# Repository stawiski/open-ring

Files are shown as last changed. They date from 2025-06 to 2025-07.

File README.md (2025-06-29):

<picture>
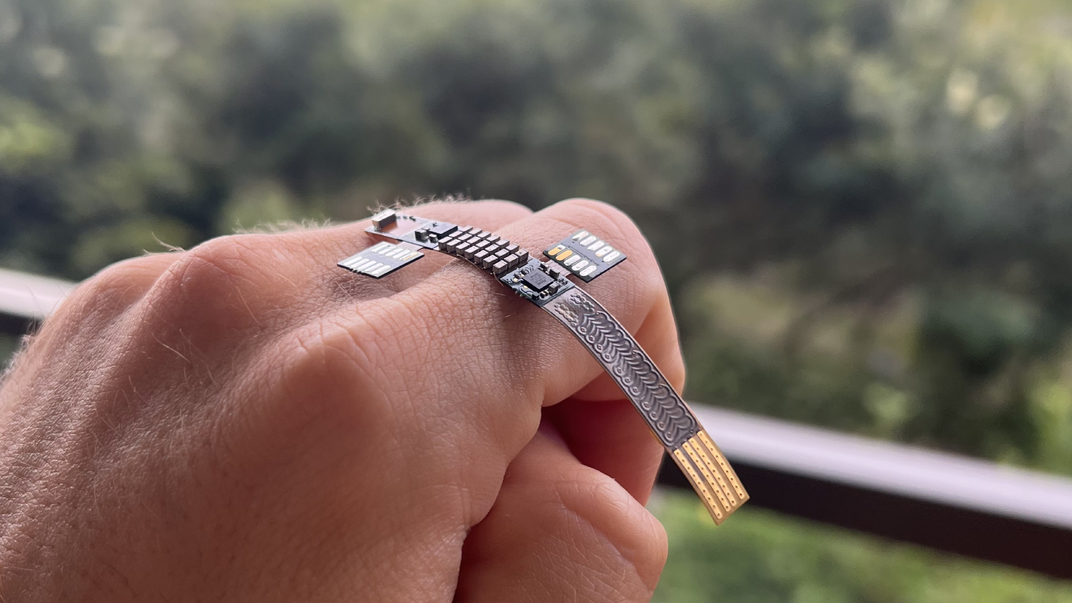
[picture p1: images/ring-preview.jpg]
Shows the Open Ring project hardware
  
</picture>

<h1 align="center">Open Ring - the open source Smart Ring project</h1>




Open Ring is an open hardware and firmware smart ring project. It is a wearable device that can be used to control any BLE connected device (e.g. your phone or computer). It can also be used as a reference for designing other smart ring projects.

# Overview

Open Ring is state-of-the-art smart ring project featuring:
- Ultra low power BLE 5.1
- Capacitive touch sensing for gestures
- Haptic feedback
- Wireless induction charging (with a separate charger)
- Wear detection

All in an absolutely tiny form factor to fit in a ring of less than 3mm thickness (a typical wedding band).
Ring sizes range from US6 to US13.

<picture>
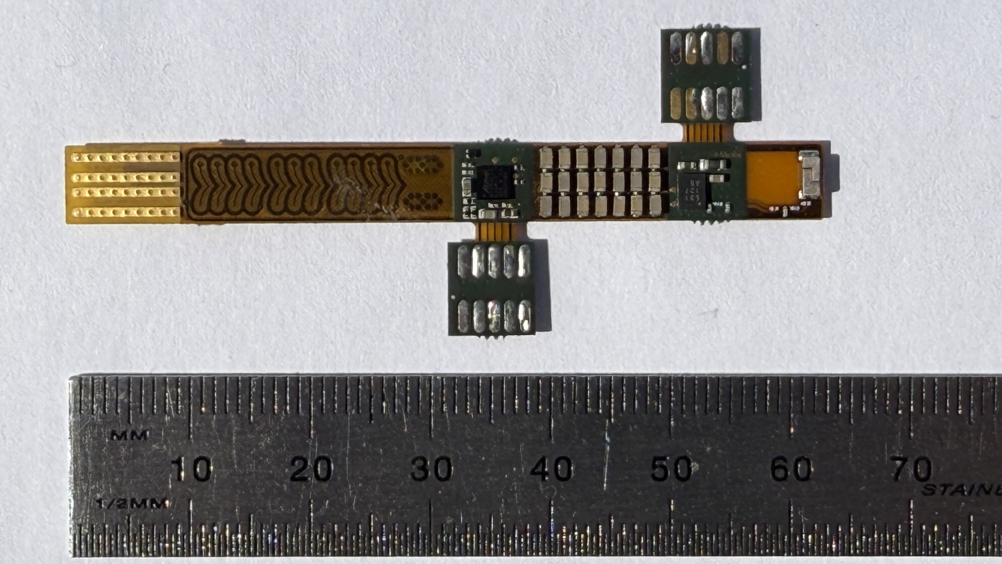
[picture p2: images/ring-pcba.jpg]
Shows the Open Ring project hardware
  
</picture>

## Status

Current project status:
- ✅ First article on Memfault has been published ([link to article](https://interrupt.memfault.com/blog/smart-ring-development-part-1))
- ✅ Hardware release

Remaining TODOs:
- Second article on Memfault about hardware development
- Third article on Memfault about firmware development + firmware release
- Update firmware builds (Docker based)
- Update README

## Hardware

Open Ring uses:
- Dialog DA14531 BLE SoC
- Atmel ATSAML10E16A MCU for capacitive touch sensing
- Texas Instruments BQ25125 power management IC
- PulseLARSEN BLE Antenna
- Macronix MX25R2035 FLASH memory
- STMicroelectronics STM32G030F6 MCU for the charger

**Take a look at the schematics**:
- [Ring schematic](./hardware/schematic_ring.pdf)
- [Charger schematic](./hardware/schematic_charger.pdf)

## Altium libraries

Many components used in this project come from Celestial Altium Library (https://github.com/issus/altium-library). Other components have been drawn from scratch. 3D step files were downloaded from the manufacturer's websites or taken from the Celestial Altium Library.

# License

Open Ring has different licenses for different parts of the project. Please see the LICENSE file for more details.

# Citation

If you use Open Ring in your research or project, please cite:

```bibtex
@software{open_ring2025,
  author = {Stawiski, Mikolaj and Meredith, Joel},
  title = {Open Ring: the open source Smart Ring project},
  year = {2025},
  publisher = {GitHub},
  url = {https://github.com/stawiski/open-ring}
}
```

<br>
<div align="center">Built proudly in Australia with love by <a href="https://www.linkedin.com/in/mstawiski/">Mikolaj Stawiski</a> and <a href="https://www.linkedin.com/in/joelmeredith/">Joel Meredith</a></div>

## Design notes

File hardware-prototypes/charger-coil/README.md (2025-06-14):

# Description

The purpose of this prototype was to compare different induction charger coil designs and pick the best one in terms of size, charging efficiency, charging area, charging distance, and number of layers.

Generally when dealing with induction charging like this, we're dealing with an air-gapped transformer. The primary coil in the charger is the transmitter and the secondary coil in the ring is the receiver.

Therefore, two coils are needed for the charging solution. We tested various coil sizes and shapes at different ring sizes (which determine the coil bending curve) to determine the best coil design for all ring sizes (US6 to US13).

The PCB was manufactured as a 2 layer flex board at 0.2mm thickness to resemble the final board stackup as close as possible.

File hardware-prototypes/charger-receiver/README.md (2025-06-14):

# Description

The purpose of this prototype was to make sure battery charging will work with the chosen BQ25125 IC. This simple PCB was basically a breakout board for the BQ25125 IC with I2C communication lines and a battery connector.

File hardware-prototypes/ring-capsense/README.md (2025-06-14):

# Description

The purpose of this prototype board was to compare different capacitive touch sense designs and pick the best one. Since the ring has a floating ground, the touch sense used mutual capactitance method (implemented by Atmel's QTouch).

The aim of this capacitive touch strip was to detect single finger taps and swipes (ideally with positional swipe for volume adjustment).

The PCB was manufactured as a 2 layer flex board at 0.2mm thickness to resemble the final board stackup as close as possible.

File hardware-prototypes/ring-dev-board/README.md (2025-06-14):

# Description

The purpose of these prototypes was to test different smart ring hardware designs and components to find the best solution for the final product, mainly:
- different capacitive touch sense designs (there was space left on the PCB to connect different touch sense strips)
- different haptic feedback motors
- different antenna positions (hence why we made separate horizontal and vertical antenna PCBs)

These prototypes don't include battery charging or power management solution, which exists in the final product.

The PCBs were manufactured as 2 layer rigid FR4 at 0.6mm thickness which doesn't resemble the final board stackup, but was as thin as possible before the board becomes fully flex.
The main bit of this PCB that needed later adjustment was the BLE antenna circuit, as the stackup influences the impedance a lot.

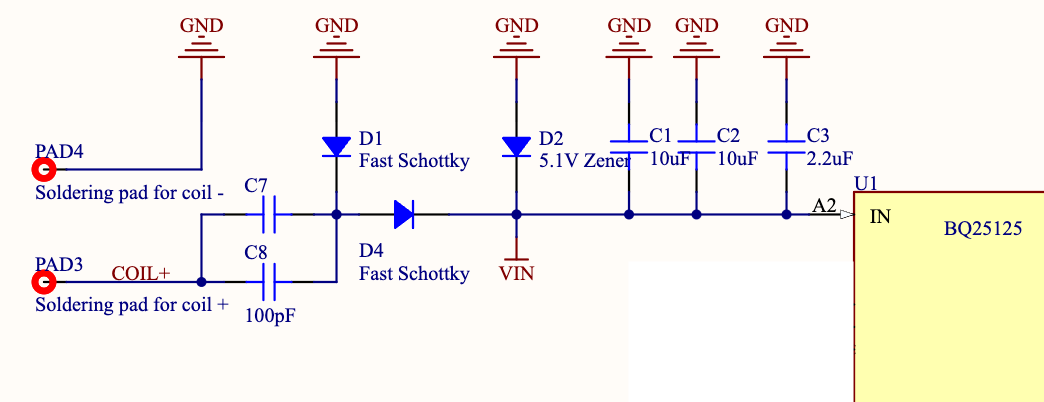
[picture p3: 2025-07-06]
images/ring-schematic-charger.png

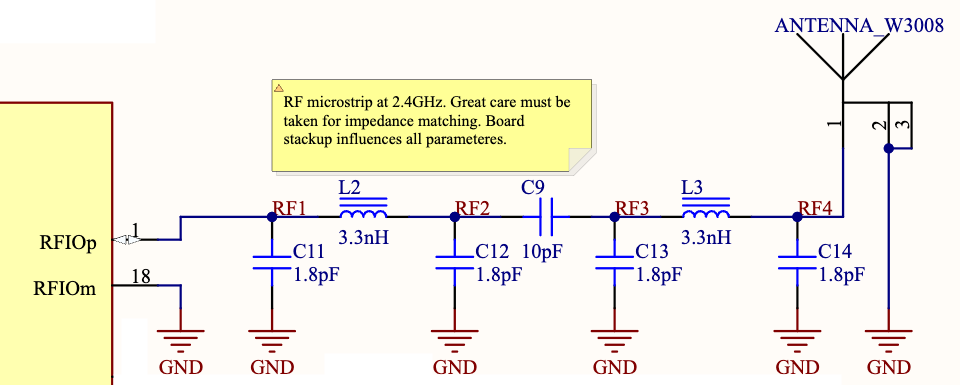
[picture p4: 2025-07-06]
images/ring-schematic-rf.png

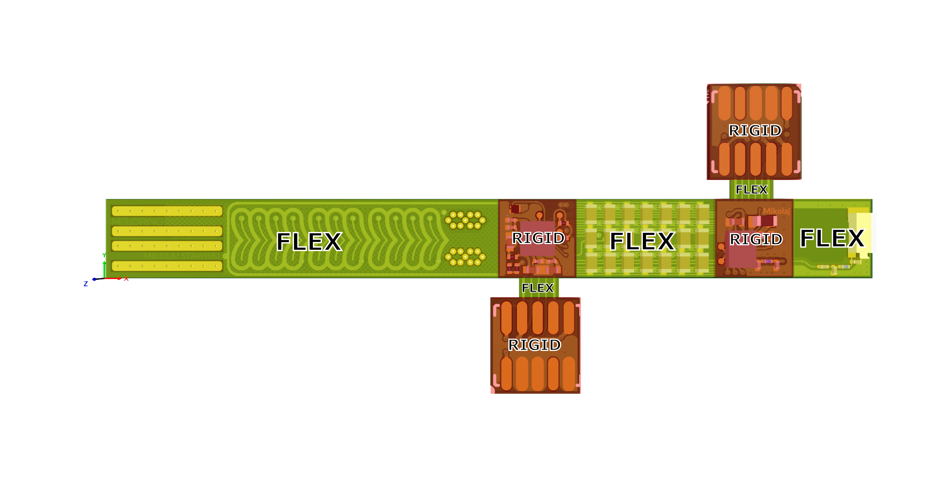
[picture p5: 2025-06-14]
hardware/ring/PCBA/preview.png

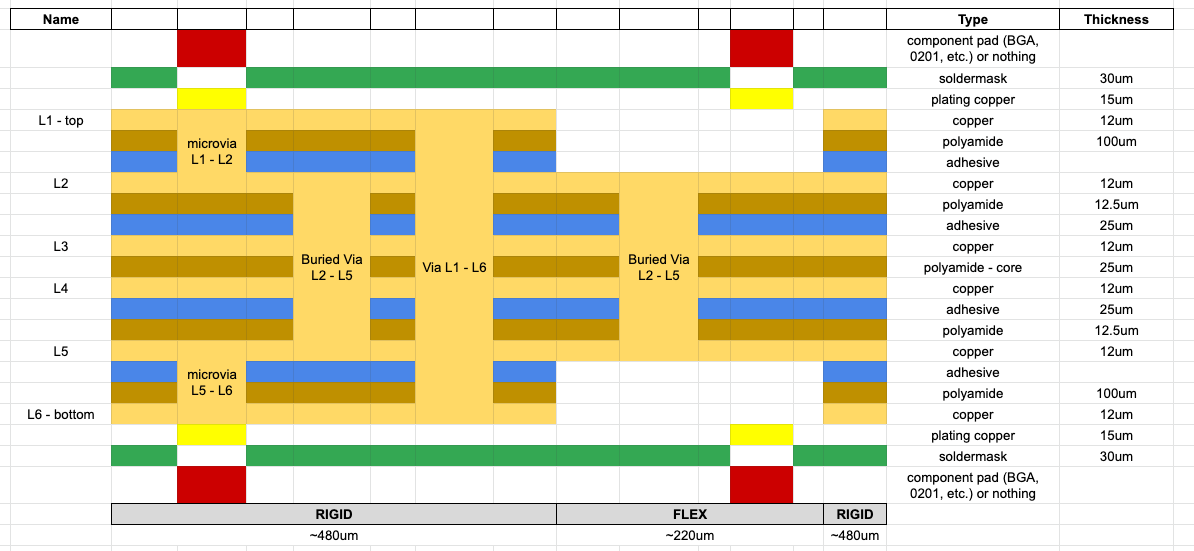
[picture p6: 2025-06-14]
images/ring-pcb-stackup.png

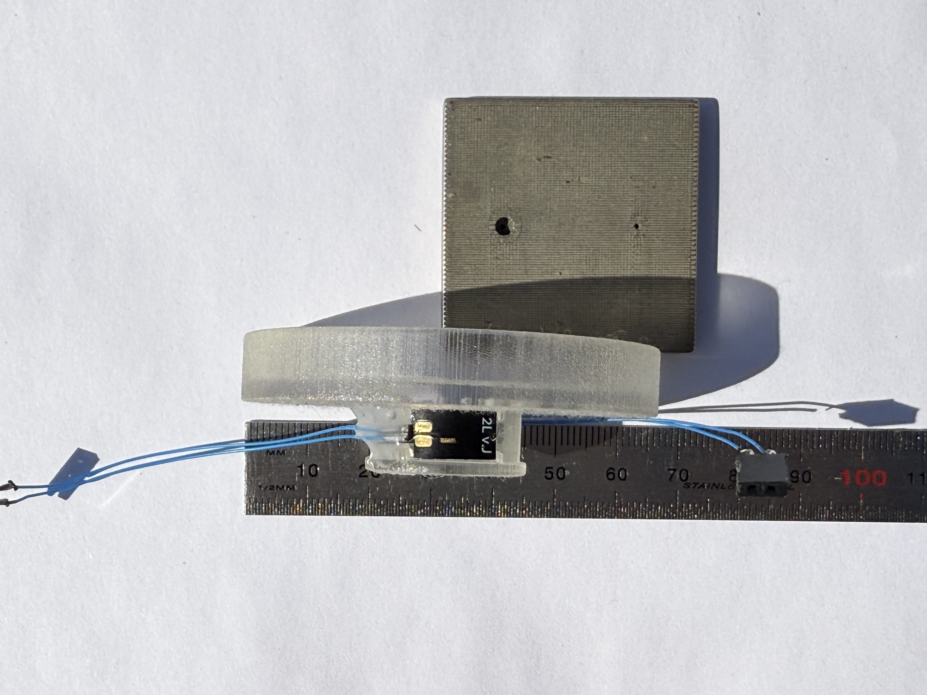
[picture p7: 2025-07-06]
images/prototype-charger-1.jpg

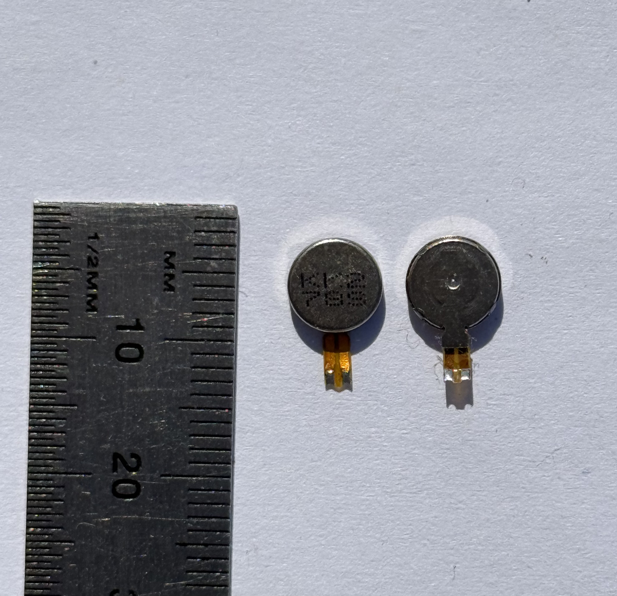
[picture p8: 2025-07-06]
images/ring-haptic-motor-1.jpg

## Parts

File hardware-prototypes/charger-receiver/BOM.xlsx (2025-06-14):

Value | Description | Designator | Footprint | Qty | Size / Dimension | Part Number | Mounting Type | Manufacturer | Distributor link 1
CAPACITORS
100nF | Capacitor SMT 0603 | C1 | 0603 | 2 | 0.063" L x 0.031" W (1.60mm x 0.80mm) |  | SMT
2.2uF | Ceramic Capacitor 2.2uF 20% 6.3V X5R 0402 | C2, C3, C6 | 0402 | 3 | 0.039" L x 0.020" W (1.00mm x 0.50mm) | GRM155R60J225ME15D | SMT | Murata | https://www.digikey.com.au/product-detail/en/murata-electronics/GRM155R60J225ME15D/490-4519-1-ND/1033278
10uF | Ceramic Capacitor 10uF 20% 10V X5R 0402 | C4, C5 | 0402 | 2 | 0.039" L x 0.020" W (1.00mm x 0.50mm) | CL05A106MP5NUNC | SMT | Samsung | https://www.digikey.com/en/products/detail/samsung-electro-mechanics/CL05A106MP5NUNC/3887108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
TBD | Ceramic Capacitor 10V X5R 0402 | C7, C8, C9, C10, C11, C12, C13, C14 | 0402 | 8 | 0.039" L x 0.020" W (1.00mm x 0.50mm) | - | SMT | - | -
100nF | Capacitor SMT 0201 | C15 | 0201 | 1 | 0.024" L x 0.012" W (0.60mm x 0.30mm) | - | SMT | - | -
RESISTORS
10k | Resistor SMT 0603 | R1, R2, R6, R7 | 0603 | 4 | 0.063" L x 0.031" W (1.60mm x 0.80mm) |  | SMT
1k | Resistor SMT 0603 | R3, R4 | 0603 | 2 | 0.063" L x 0.031" W (1.60mm x 0.80mm) |  | SMT
200k | Resistor SMT 0603 | R5 | 0603 | 1 | 0.063" L x 0.031" W (1.60mm x 0.80mm) |  | SMT
TBD | Resistor SMT 0603 | R8, R9 | 0603 | 2 | 0.063" L x 0.031" W (1.60mm x 0.80mm) | - | SMT | -
TBD | Resistor SMT 0402 | R10, R11 | 0402 | 2 | 0.039" L x 0.020" W (1.00mm x 0.50mm) | - | SMT | -
OTHER PASSIVES
2.2uH | Inductor fixed 2.2uH 20% 500mA 180mOhm 0603 | L1 | 0603 | 1 | 0.063" L x 0.031" W (1.60mm x 0.80mm) | MLZ1608N2R2LT000 | SMT | TDK | https://www.digikey.com.au/product-detail/en/tdk-corporation/MLZ1608N2R2LT000/445-6754-1-ND/2523575
SEMICONDUCTORS
Fast Schottky | Diode SMT 0402 | D1, D3 | CLP1006-2L | 2 | 0.039" L x 0.020" W (1.00mm x 0.50mm) | VSKY05301006 | SMT | Vishay | https://www.digikey.com/en/products/detail/vishay-general-semiconductor-diodes-division/VSKY05301006-G4-08/7390852
Fast Schottky | Diode SMT 0201 | D2, D4 | CLP0603-2M | 2 | 0.024" L x 0.012" W (0.60mm x 0.30mm) | VSKY02300603 | SMT | Vishay | https://www.digikey.com/en/products/detail/vishay-general-semiconductor-diodes-division/VSKY02300603-G4-08/7390849
INTEGRATED CIRCUITS
BQ25125 | BQ25125 Low IQ Highly Integrated Battery Charge Management Solution For Wearables and IoT | U1 | BQ25125-DSBGA25 | 1 |  | BQ25125 | SMT | TI | https://www.digikey.com/en/products/detail/texas-instruments/BQ25125YFPR/10273214
LSF0102-Q1 | Automotive 2-Channel Auto Bidirectional Multi-Voltage Level Translator | U2 | 8-VSSOP | 1 |  | LSF0102QDCURQ1 | SMT | TI | https://www.digikey.com/en/products/detail/texas-instruments/LSF0102QDCURQ1/9343347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
CONNECTORS
Receiver Coil | FPC connector 5-pin generic | J12 | FPC_5PIN_0545500571 | 1 |  |  | SMT
4-pin goldpin | Connector 4-pin generic | J6 J7 | HEADER_4PIN_0022272041 | 2 | - |  | THT
2-pin goldpin | Connector 2-pin generic | - | HEADER_2PIN_0022272021 | 10 | - |  | THT
OTHER
Testpoint | Testpoint for measuring at the PCB | TP1, TP2, TP3, TP4, TP5, TP6, TP7, TP8 | Testpoint 2mm | 8 |  |  | -

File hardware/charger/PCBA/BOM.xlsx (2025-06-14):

Designator | Qty | Part Number | Value | Description | Footprint | Tolerance | Manufacturer | Distributor link
R1, R6 | 2 |  | 47R | Resistor SMT 0402 | SMD_RESISTOR_0402 | 5%
R2, R7, R17, R19 | 4 |  | 100k | Resistor SMT 0402 | SMD_RESISTOR_0402 | 5%
R3, R4, R5, R27, R28 | 5 |  | 10k 1% | Resistor SMT 0402 | SMD_RESISTOR_0402 | 1%
R8, R9 | 2 |  | 5.1k | Resistor SMT 0402 | SMD_RESISTOR_0402 | 5%
R10 | 1 |  | 10k 5% | Resistor SMT 0402 | SMD_RESISTOR_0402 | 5%
R11 | 1 |  | 300k | Resistor SMT 0402 | SMD_RESISTOR_0402 | 5%
R12 | 1 |  | 240k 1% | Resistor SMT 0402 | SMD_RESISTOR_0402 | 1%
R13, R15 | 2 |  | TBD | Resistor SMT 0402 | SMD_RESISTOR_0402 | 5%
R14 | 1 |  | 0.2R 1% | Resistor SMT 1206 | SMD_RESISTOR_1206 | 1%
R16, R18 | 2 |  | 14.3k 1% | Resistor SMT 0402 | SMD_RESISTOR_0402 | 1%
R20, R21 | 2 |  | 0R | Resistor SMT 0603 | SMD_RESISTOR_0603 | -
R22, R23 | 2 |  | 100k 1% | Resistor SMT 0402 | SMD_RESISTOR_0402 | 1%
R24 | 1 |  | 51k | Resistor SMT 0402 | SMD_RESISTOR_0402 | 5%
R25 | 1 |  | 117k 1% | Resistor SMT 0402 | SMD_RESISTOR_0402 | 1%
R26 | 1 |  | 13.3k 1% | Resistor SMT 0402 | SMD_RESISTOR_0402 | 1%
C1, C4, C5, C6, C18, C19, C24 | 7 | GRM155R71H104KE14D | 100nF | Capacitor SMT 0402 | SMD_CAPACITOR_0402 | 10% | Murata | https://www.digikey.com/en/products/detail/murata-electronics/GRM155R71H104KE14D/4906220
C2, C3, C7, C22, C23, C25 | 6 | CL10A225KP8NNNC | 2.2uF | Capacitor SMT 0603 | SMD_CAPACITOR_0603 | 10% | Samsung | https://www.digikey.com/en/products/detail/samsung-electro-mechanics/CL10A225KP8NNNC/3886743
C8, C20 | 2 |  | 10nF | Capacitor SMT 0402 | SMD_CAPACITOR_0402 | 10% | Murata | https://www.digikey.com/en/products/detail/murata-electronics/GRM155R71H104KE14D/4906220, [NoValue]
C10, C11, C12, C13 | 4 |  | TBD | Capacitor SMT 1206 | SMD_CAPACITOR_1206
C16 | 1 |  | 100nF | Capacitor SMT 0603 | SMD_CAPACITOR_0603 | 10%
C17 | 1 | CL21A226MOCLRNC | 22uF | Capacitor SMT 0805 | SMD_CAPACITOR_0805 | 20% | Samsung | https://www.digikey.com/en/products/detail/samsung-electro-mechanics/CL21A226MOCLRNC/5961264
C21 | 1 |  | 10pF | Capacitor SMT 0402 | SMD_CAPACITOR_0402 | 10%
C26, C27 | 2 | C3216X5R1H106K160AB | 10uF | Capacitor SMT 1206 | SMD_CAPACITOR_1206 | 10% | TDK | https://www.digikey.com/en/products/detail/tdk-corporation/C3216X5R1H106K160AB/2443476
C28 | 1 |  | 120pF | Capacitor SMT 0402 | SMD_CAPACITOR_0402 | 10% | Murata
D1 | 1 | SMBJ5.0A | SMBJ5.0A | Generic TVS Diode | SMD_DIODE_DO-214AA |  | Bourns | https://www.digikey.com/en/products/detail/bourns-inc/SMBJ5-0A/2254202
D2 | 1 | MBR0540T1G | MBR0540T1G | Diode Schottky | SOD-123 |  |  | https://www.digikey.com/en/products/detail/on-semiconductor/MBR0540T1G/917967
F1 | 1 | C1Q500 | C1Q500 | Generic Fuse | SMD_RESISTOR_1206 |  | Bel Fuse Inc. | https://www.digikey.com/en/products/detail/bel-fuse-inc/C1Q-500/615155
L1 | 1 | MLP2520S100ST0S1 | 10uH | Inductor DC/DC | 1008_MLP2520 | 20% | TDK | https://www.digikey.com/en/products/detail/MLP2520S100ST0S1/445-9507-1-ND/3909680?itemSeq=362222387
LED1 | 1 | APB3227 | APB3227 | APB3227 LED | 1210_LED |  | Kingbright
Q2 | 1 | NX7002BK | NX7002BK | Power N-MOSFET | SOT23-3-GSD
U1 | 1 | STM32G030F6 | STM32G030F6 | MCU | TSSOP20 |  | STM | https://www.digikey.com/en/products/detail/stmicroelectronics/STM32G030F6P6/10326686
U2 | 1 | TPS79933DDCR‎ | TPS799 | LDO 3.3V | SO23-5 |  | TI
U3 | 1 | TPS25200 | TPS25200 | eFuse for USB-C | WSON6 |  | TI | https://www.digikey.com/en/products/detail/texas-instruments/TPS25200DRVT/4840667
U4 | 1 | MAX4073 | MAX4073 | Current Sense IC | SOT23-6 |  | Maxim Integrated
U5 | 1 | INA183 | INA183 | Current Sense IC | SO23-5 |  | TI | https://www.digikey.com.au/product-detail/en/texas-instruments/INA183A1IDBVR/296-INA183A1IDBVRTR-ND/13896392
U6, U7 | 2 | FAN5622 | FAN5622 | LED Driver | SOT23-6 |  | Failchild | https://www.digikey.com/en/products/detail/on-semiconductor/FAN5622SX/2509485
U8 | 1 | LMR64010XMF | LMR64010 | DC/DC Boost IC | SO23-5 |  | TI | https://www.digikey.com/en/products/detail/LMR64010XMFX%2fNOPB/296-38771-1-ND/5125873
X1 | 1 |  | Oscillator TBD | Oscillator | ECS-2520MVLC
J4 | 1 | 1054500101 | USB-C | USB-C connector | USBC_105450-0101 |  | Molex | https://www.digikey.com/en/products/detail/molex/1054500101/5843890
J5 | 1 | FTSH-105-01-L-DV-K | SWD | 10-pin ARM SWD connector for debugging | CONN_SWD_10PIN |  | Samtec
J1 | 1 |  | Receiver Coil | FPC connector 5-pin generic | FPC_5PIN_0545500571
J3 | 1 |  | DEBUG UART | Connector 4-pin generic | HEADER_4PIN_0022272041
TP1, TP2, TP3, TP4, TP5, TP6, TP7 | 7 |  | Testpoint | Testpoint | Testpoint 2mm

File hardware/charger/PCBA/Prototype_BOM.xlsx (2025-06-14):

Designator | Qty | Part Number | Value | Description | Footprint | Manufacturer | Distributor link
R1, R6 | 2 |  | 47R 5% | Resistor SMT 0402 | SMD_RESISTOR_0402
R2, R7, R17, R19, R22, R23 | 6 |  | 100k 1% | Resistor SMT 0402 | SMD_RESISTOR_0402
R8, R9 | 2 |  | 5.1k 5% | Resistor SMT 0402 | SMD_RESISTOR_0402
R10 | 1 |  | 10k 5% | Resistor SMT 0402 | SMD_RESISTOR_0402
R11 | 1 |  | 300k 5% | Resistor SMT 0402 | SMD_RESISTOR_0402
R12 | 1 |  | 240k 1% | Resistor SMT 0402 | SMD_RESISTOR_0402
R13 | 1 |  | 0R | Resistor SMT 0402 | SMD_RESISTOR_0402
R14 | 1 | CRM1206-FX-R220ELF | 0.22R 1% | Resistor SMT 1206 | SMD_RESISTOR_1206 | Bourns | https://www.digikey.com/en/products/detail/bourns-inc/CRM1206-FX-R220ELF/4698307
R16, R18 | 2 |  | 14.3k 1% | Resistor SMT 0402 | SMD_RESISTOR_0402
R20 | 1 |  | 0R | Resistor SMT 0603 | SMD_RESISTOR_0603
R24 | 1 |  | 51k 5% | Resistor SMT 0402 | SMD_RESISTOR_0402
R25 | 1 |  | 117k 1% | Resistor SMT 0402 | SMD_RESISTOR_0402
R26 | 1 |  | 15k 1% | Resistor SMT 0402 | SMD_RESISTOR_0402
C1, C4, C5, C6, C18, C24 | 6 | GRM155R71H104KE14D | 100nF 10% X5R 10V | Capacitor SMT 0402 | SMD_CAPACITOR_0402 | Murata | https://www.digikey.com/en/products/detail/murata-electronics/GRM155R71H104KE14D/4906220
C2, C3, C7, C22, C23, C25 | 6 | CL10A225KP8NNNC | 2.2uF 10% X5R 10V | Capacitor SMT 0603 | SMD_CAPACITOR_0603 | Samsung | https://www.digikey.com/en/products/detail/samsung-electro-mechanics/CL10A225KP8NNNC/3886743
C8 | 1 |  | 10nF 10% X5R 10V | Capacitor SMT 0402 | SMD_CAPACITOR_0402 | Murata
C16 | 1 |  | 100nF 10% X5R 50V | Capacitor SMT 0603 | SMD_CAPACITOR_0603 | Murata
C17 | 1 | CL21A226MOCLRNC | 22uF 20% X5R 16V | Capacitor SMT 0805 | SMD_CAPACITOR_0805 | Samsung | https://www.digikey.com/en/products/detail/samsung-electro-mechanics/CL21A226MOCLRNC/5961264
C26, C27 | 2 | C3216X5R1H106K160AB | 10uF 10% X5R 50V | Capacitor SMT 1206 | SMD_CAPACITOR_1206 | TDK | https://www.digikey.com/en/products/detail/tdk-corporation/C3216X5R1H106K160AB/2443476
C28 | 1 |  | 120pF 10% X5R 50V | Capacitor SMT 0402 | SMD_CAPACITOR_0402 | Murata
D1 | 1 | SMBJ5.0A | SMBJ5.0A | TVS Diode | SMD_DIODE_DO-214AA | Bourns | https://www.digikey.com/en/products/detail/bourns-inc/SMBJ5-0A/2254202
D2 | 1 | MBR0540T1G | MBR0540T1G | Schottky Diode | SOD-123 |  | https://www.digikey.com/en/products/detail/on-semiconductor/MBR0540T1G/917967
F1 | 1 | C1Q500 | C1Q500 | Fuse | SMD_RESISTOR_1206 | Bel Fuse Inc. | https://www.digikey.com/en/products/detail/bel-fuse-inc/C1Q-500/615155
L1 | 1 | MLP2520S100ST0S1 | 10uH | Inductor DC/DC | 1008_MLP2520 | TDK | https://www.digikey.com/en/products/detail/MLP2520S100ST0S1/445-9507-1-ND/3909680?itemSeq=362222387
LED1 | 1 | APB3227SURKZGKC | APB3227 | Double LED | 1210_LED | Kingbright | https://www.digikey.com/en/products/detail/kingbright/APB3227SURKZGKC/7318961
U1 | 1 | STM32G030F6 | STM32G030F6 | MCU | TSSOP20 | STM | https://www.digikey.com/en/products/detail/stmicroelectronics/STM32G030F6P6/10326686
U2 | 1 | TPS79933DDCR‎ | TPS799 | LDO 3.3V | SO23-5 | TI | https://www.digikey.com/en/products/detail/texas-instruments/TPS79933DDCR/717449
U3 | 1 | TPS25200 | TPS25200 | IC for USB-C protection | WSON6 | TI | https://www.digikey.com/en/products/detail/texas-instruments/TPS25200DRVT/4840667
U4 | 1 | MAX4073FAUT | MAX4073 | Current Sense IC | SOT23-6 | Maxim Integrated | https://www.digikey.com/en/products/detail/maxim-integrated/MAX4073FAUT-T/1705118
U6, U7 | 2 | FAN5622 | FAN5622 | LED Driver IC | SOT23-6 | Failchild | https://www.digikey.com/en/products/detail/on-semiconductor/FAN5622SX/2509485
U8 | 1 | LMR64010XMF | LMR64010 | DC/DC Boost IC | SO23-5 | TI | https://www.digikey.com/en/products/detail/LMR64010XMFX%2fNOPB/296-38771-1-ND/5125873
X1 | 1 | ECS-2520MVLC-135.6-BN-TR | 13.56MHz | Oscillator | ECS-2520MVLC | ECS | https://www.digikey.com/en/products/detail/ecs-inc/ECS-2520MVLC-135-6-BN-TR/12746085
J4 | 1 | 1054500101 | USB-C | USB-C connector | USBC_105450-0101 | Molex | https://www.digikey.com/en/products/detail/molex/1054500101/5843890
J5 | 1 | FTSH-105-01-L-DV-K | SWD | 10-pin ARM SWD connector for debugging | CONN_SWD_10PIN | Samtec | https://www.digikey.com/en/products/detail/samtec-inc/FTSH-105-01-L-DV-K/1875039
TP1, TP2, TP3, TP4, TP5, TP6, TP7 | 7 |  | Testpoint | Testpoint | Testpoint 2mm

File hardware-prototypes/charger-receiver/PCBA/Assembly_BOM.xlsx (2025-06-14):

Designator | Value | Description | Footprint | Qty | Size / Dimension | Part Number | Mounting Type | Manufacturer | Distributor link 1
C1 | 100nF | Capacitor SMT 0603 | 0603 | 1 | 0.063" L x 0.031" W (1.60mm x 0.80mm) |  | SMT
C2, C3, C6 | 2.2uF | Ceramic Capacitor 2.2uF 20% 6.3V X5R 0402 | 0402 | 3 | 0.039" L x 0.020" W (1.00mm x 0.50mm) | GRM155R60J225ME15D | SMT | Murata | https://www.digikey.com.au/product-detail/en/murata-electronics/GRM155R60J225ME15D/490-4519-1-ND/1033278
C4, C5 | 10uF | Ceramic Capacitor 10uF 20% 10V X5R 0402 | 0402 | 2 | 0.039" L x 0.020" W (1.00mm x 0.50mm) | CL05A106MP5NUNC | SMT | Samsung | https://www.digikey.com/en/products/detail/samsung-electro-mechanics/CL05A106MP5NUNC/3887108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
C15, C16 | 100nF | Capacitor SMT 0201 | 0201 | 2 | 0.024" L x 0.012" W (0.60mm x 0.30mm) | - | SMT | - | -
R1, R2 | 10k | Resistor SMT 0603 | 0603 | 2 | 0.063" L x 0.031" W (1.60mm x 0.80mm) |  | SMT
R3, R4 | 1k | Resistor SMT 0603 | 0603 | 2 | 0.063" L x 0.031" W (1.60mm x 0.80mm) |  | SMT
R5 | 200k | Resistor SMT 0603 | 0603 | 1 | 0.063" L x 0.031" W (1.60mm x 0.80mm) |  | SMT
L1 | 2.2uH | Inductor fixed 2.2uH 20% 500mA 180mOhm 0603 | 0603 | 1 | 0.063" L x 0.031" W (1.60mm x 0.80mm) | MLZ1608N2R2LT000 | SMT | TDK | https://www.digikey.com.au/product-detail/en/tdk-corporation/MLZ1608N2R2LT000/445-6754-1-ND/2523575
U1 | BQ25125 | BQ25125 Low IQ Highly Integrated Battery Charge Management Solution For Wearables and IoT | BQ25125-DSBGA25 | 1 |  | BQ25125 | SMT | TI | https://www.digikey.com/en/products/detail/texas-instruments/BQ25125YFPR/10273214
U2 | LSF0102-Q1 | Automotive 2-Channel Auto Bidirectional Multi-Voltage Level Translator | 8-VSSOP | 1 |  | LSF0102QDCURQ1 | SMT | TI | https://www.digikey.com/en/products/detail/texas-instruments/LSF0102QDCURQ1/9343347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

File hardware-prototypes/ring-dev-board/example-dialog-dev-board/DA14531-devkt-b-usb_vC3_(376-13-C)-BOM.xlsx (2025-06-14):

 |  |  |  |  |  |  |  |  |  | MANDATORY
 |  |  |  |  |  |  |  |  |  | EXAMPLE, FREE OF CHOICE. USE IDENTICAL OR SUPERIOR SPECIFICATION PART NUMBER
 |  |  |  |  |  |  |  |  |  | (Must be RoHS and latest REACH compliant)
 | Dialog_Number | Part_type | Quantity | Description | Environmental | Part Reference | Value | Layout_PCB_Footprint | PCB Footprint | Manufacturer | Manufacturer_Part_Number | Avail. On Distributor | Check Avail. | Comments
 |  |  |  | CAPACITOR
1 | 030-110209 | Ceramic | 2 | CAP CER 1.8pF ±0.25pF 50V C0G (NP0) 0201 | RoHS/No SVHC (15-Jan-2019) | Z6 Z8 | 1.8pF | 0201 | C0603mm | Murata | GRM0335C1H1R8CA01D | https://www.findchips.com/detail/GRM0335C1H1R8CA01D/2213-Murata%20Manufacturing%20Co%20Ltd?quantity=1 | D / M / F
2 | 030-110198 | Ceramic | 1 | CAP CER 2.4PF±0.1pF 50V C0G/NP0 0402 | RoHS/ REACH compl. (15 Jan 2019) | Z2 | 2.4pF | 0402 | C1005 | Murata | GJM1555C1H2R4BB01D | https://www.findchips.com/detail/GJM1555C1H2R4BB01D | D / M / F
3 | 030-110146 | Ceramic | 2 | CAP CER 10pF ±5% 50V C0G/NP0, 0402 | RoHS/ REACH compl. (15 Jan 2019) | C29 Z5 | 10pF | 0402 | C1005 | Murata | GCM1555C1H100JA16D | https://www.findchips.com/detail/GCM1555C1H100JA16D/2213-Murata%20Manufacturing%20Co%20Ltd?quantity=1 | D / M / F
4 | 030-110073 | Ceramic | 2 | CAP CERAMIC 18PF ±5% 50V C0G/NP0 0402 | RoHS/ REACH compl. (15 Jan 2019) | C30 C31 | 18pF | 0402 | C1005 | Taiyo Yuden | UMK105CG180JV-F | https://www.findchips.com/detail/UMK105CG180JV-F/2462-TAIYO%20YUDEN?quantity=1 | D / M
5 | 030-110194 | Ceramic | 1 | CAP CER 10nF ±10% 25V X7R 0402 | RoHS/No SVHC (15-Jan-2018) | C32 | 10nF | 0402 | C1005 | Murata | GCM155R71E103KA37D | https://www.findchips.com/detail/GCM155R71E103KA37D/2213-Murata%20Manufacturing%20Co%20Ltd?quantity=1 | D/M/F
6 | 030-110192 | Ceramic | 11 | CAP CER. 100nF ±10% 16V X7R 0402 | RoHS/ REACH compl. (15 Jan 2019) | C7 C9 C10 C19 C20 C21 C22 C23 C24 C25 C26 | 100nF | 0402 | C1005 | Murata | GCM155R71C104KA55D | https://www.findchips.com/detail/GCM155R71C104KA55D/2213-Murata%20Manufacturing%20Co%20Ltd?quantity=1 | D / M / F
7 | 030-110202 | Ceramic | 3 | CAP CERAMIC 1.0UF 10V X5R ±20% 0402 | RoHS/No SVHC (27-Jun-2018) | C3 C4 C5 | 1.0uF | 0402 | C1005 | Murata | GRM153R61A105ME95D | https://www.findchips.com/detail/GRM153R61A105ME95D | D / M
8 | 030-110191 | Ceramic | 2 | CAP CER 2.2UF ±20% 25V X5R 0402 | RoHS/ REACH compl. (15 Jan 2019) | C1 C6 | 2.2UF | 0402 | C1005 | Murata | GRM155R61E225ME15D | https://www.findchips.com/detail/GRM155R61E225ME15D/2213-Murata%20Manufacturing%20Co%20Ltd?quantity=1 | D / M
9 | 030-110196 | Ceramic | 3 | CAP CER 10UF ±20% 6.3V X5R 0402 | RoHS/ REACH compl. (15 Jan 2019) | C2 C27 C28 | 10uF | 0402 | C1005 | Murata | GRJ155R60J106ME11D | https://www.findchips.com/detail/GRJ155R60J106ME11D/2213-Murata%20Manufacturing%20Co%20Ltd?quantity=1 | D / M / F
 |  |  |  | RESISTOR
10 | 030-010396 | Resistor | 3 | RES 0.0 OHM 1/10W 0402 | RoHS Compliant with exemption 7(C)-I / REACH compl. (15 Jan 2019) | R19 R42 R50 | 0 | 0402 | R1005 | Panasonic | ERJ-2GE0R00X | https://www.findchips.com/detail/ERJ-2GE0R00X | D / M/F
11 | 030-010460 | Resistor | 14 | RES 36 OHM ±1% 0.05W, ± 200ppm/°C -0201 | RoHS/No SVHC (15-Jan-2019) | R1 R2 R3 R4 R5 R6 R7 R8 R9 R10 R11 R12 R40 R41 | 36 | 0201 | R0603mm | Yageo | RC0201FR-0736RL | https://www.findchips.com/detail/RC0201FR-0736RL | D / M
12 | 030-010072 | Resistor | 3 | RES 150 OHM 1/16W 5% 100ppm/°C 0402 | RoHS Compliant with exemption 7(C)-I & 10(a) / REACH compl. (27 Jun 2018) | R22 R31 R32 | 150 | 0402 | R1005 | Yageo | RC0402JR-07150RL | https://www.findchips.com/detail/RC0402JR-07150RL | D / M
13 | 030-010121 | Resistor | 2 | RES 270 OHM 1/16W 5% 100ppm/°C 0402 | RoHS Compliant with exemption 7(C)-I & 10(a) / REACH compl. (27 Jun 2018) | R15 R16 | 270 | 0402 | R1005 | Yageo | RC0402JR-07270RL | https://www.findchips.com/detail/RC0402JR-07270RL | D / M /F
14 | 030-010146 | Resistor | 7 | RES 330 OHM 1/16W 5% ±200ppm/°C-0402 | RoHS with exemption 7(C)-I/REACH compl. (15 Jan 2019) | R24 R25 R28 R29 R34 R35 R38 | 330 | 0402 | R1005 | Vishay | CRCW0402330RJNED | https://www.findchips.com/detail/CRCW0402330RJNED | D / M / F
15 | 030-010019 | Resistor | 1 | RES 1.0 Kohm 1/16W 5% ±200ppm/°C-0402 | RoHS Compliant with exemption 7(C)-I / REACH compl. (15 Jan 2019) | R14 | 1.00k | 0402 | R1005 | Vishay | CRCW04021K00JNED | https://www.findchips.com/detail/CRCW04021K00JNED | D / F
16 | 030-010093 | Resistor | 1 | RES 2.2 Kohm 100mW 5% 0402 | RoHS Compliant with exemption 7(C)-I / REACH compl. (15 Jan 2019) | R27 | 2.2k | 0402 | R1005 | Panasonic | ERJ-2GEJ222X | https://www.findchips.com/detail/ERJ-2GEJ222X | D / M
17 | 030-010169 | Resistor | 3 | RES 4.7 Kohm 1/16W 5% 0402 | RoHS Compliant with exemption 7(C)-I & 10(a) / REACH compl. (27 Jun 2018) | R23 R37 R48 | 4.7k | 0402 | R1005 | Yageo | RC0402JR-074K7L | https://www.findchips.com/detail/RC0402JR-074K7L | D / M
18 | 030-010418 | Resistor | 1 | RES SMD 6.8K OHM 5% 1/16W 100ppm/°C 0402 | RoHS Compliant with exemption 7(C)-I & 10(a) / REACH compl. (27 Jun 2018) | R39 | 6.8k | 0402 | R1005 | Yageo | RC0402JR-076K8L | https://www.findchips.com/detail/RC0402JR-076K8L | D / M /F
19 | 030-010367 | Resistor | 5 | RES 10.0 Kohm 5% 1/16W 100ppm/°C 0402 | RoHS/ REACH compl. (27 Jun 2018) | R26 R30 R43 R44 R45 | 10.0k | 0402 | R1005 | Yageo | RC0402JR-0710KL | https://www.findchips.com/detail/RC0402JR-0710KL | D / M / F
20 | 030-010447 | Resistor | 3 | RES SMD 100K OHM 5% 1/10W 0402 | RoHS Compliant with exemption 7(C)-I / REACH compl. (15 Jan 2019) | R36 R46 R49 | 100.0k | 0402 | R1005 | Panasonic | ERJ-2GEJ104X | https://www.findchips.com/detail/ERJ-2GEJ104X | D / M / F
 |  |  |  | SEMICONDUCTOR
21 | 030-730035 | Protection | 2 | TVS DIODE 24V 42 V, 26.5V Breakd. 0402C/SOD923F | RoHS/ REACH compl. (15 Jan 2019) | D1 D6 | CPDQC24VEU-HF | 0402 with polarity mark | D1005 | Comchip Technology | CPDQC24VEU-HF | https://media.digikey.com/pdf/Data%20Sheets/Comchip%20PDFs/CPDQC24VEU-HF.pdf | D / M
22 | 030-310077 | Diode | 1 | DIODE ZENER Vz:5.6V Pd:300mW 40 Ohms ±7%(SOT-23-3) | RoHS/ REACH compl. (15 Jan 2019) | D2 | BZX84C5V6-7-F | SOT-23-3 | SOT95P290X130-3N | Diodes Inc. | BZX84C5V6-7-F | https://www.findchips.com/detail/BZX84C5V6-7-F | D / M
23 | 030-730034 | Protection | 2 | TVS DIODE Biderctional 5V 20V 6V Breakd. 0402/SOD923F | RoHS/ REACH compl. (15 Jan 2019) | D3 D4 | CPDQC5V0CSP-HF | 0402 without polarity mark | D1005B | Comchip Technology | CPDQC5V0CSP-HF | https://www.findchips.com/detail/CPDQC5V0CSP-HF | D / M
24 | 030-320015 | Led | 1 | LED ORANGE DIFF. Vf: 2.2V/20mA/14 mcd/160° (0603) | RoHS/? | D7 | Led_Orange | 0603 | Led1608 | Osram | LO L29K-H2L1-24-Z | https://www.findchips.com/detail/LOL29K-H2L1-24-Z | A
25 | 030-320002 | Led | 1 | LED GREEN CLEAR Vf: 2V/30mA/40 mcd/140° (0603) | RoHS/ REACH compl. (15 Jan 2019) | D8 | Led_Green | 0603 | Led1608 | Wurth Electronics | 150060VS75000 | https://www.findchips.com/detail/150060VS75000 | D/M
26 | 030-340037 | Transistor | 1 | TRANSISTOR PNP Vceo:-45V, Ic:-500mA 160~400hFE @-100mA (SOT23) -nxp | RoHS/ REACH compl. (15 Jan 2019) | Q1 | BC807-25_215 | SOT23-3 | SOT95P290X130-3N | NXP | BC807-25,215 | https://www.findchips.com/detail/BC807-25,215 | D/F
27 | 030-330038 | Mosfet | 1 | MOSFET-P Vdss:-30V/Vgss:±20V/Id:-2.9~-3.8A /Pd:1.08W (SOT-23) | RoHS/ REACH compl. (15 Jan 2019) | Q2 | DMP3099L-7 | TO-236-3, SC-59, SOT-23-3 | SOT915P290X110-3N | Diodes Inc. | DMP3099L-7 | https://www.findchips.com/detail/DMP3099L-7 | D/F
 |  |  |  | CONNECTOR-SWITCHES
28 | 030-660008 | USB Connector | 1 | USB 2.0 CONN PLUG Type A 4POS,SMD R/A | RoHS/ REACH compl. (15 Jan 2019) | J1 | Type A Through usb | USB_A_MOLEX480372200 | USB_A_MOLEX480372200 | Molex Inc | 48037-2200 | https://www.findchips.com/detail/48037-2200 | D/ M /F
29 | 030-520039 | Switch | 2 | SWITCH TACTILE SPST-NO 0.02A, 15VDC smd/RA, Operating Force:160GF (3.8×1.9 mm) | RoHS/ REACH compl. (15 Jan 2019) | SW1, SW2 | EVP-AKE31A | 3.8×1.9 mm Side-op SMD | Sw_EVPAKE31A | Panasonic | EVP-AKE31A | https://www.findchips.com/detail/EVP-AKE31A | D/M
30 | 030-520043 | Switch | 1 | SWITCH SLIDE DIP SPST 25MA 24V 12 SWITCHES- (16.41X8.5mm) | RoHS/ REACH compl. (15 Jan 2019) | S1 | 218-12LPST | 16.41X8.5mm | dipsw12_127_gw | CTS Electrocomponents | 218-12LPST | D / M | https://www.findchips.com/detail/218-12LPST
31 | 030-710051 | Mechanical Parts | 1 | MECH 1206 PROBE PAD -PC Test Point | RoHS/No SVHC (27-Jun-2018) | TP28 | TP_RCW-0C | RCW-0C | tp3216 | TE Connectivity AMP Connectors | RCW-0C | https://www.findchips.com/detail/RCW-0C | D / M /F
 |  |  |  | INDUCTOR -FB
32 | 030-210220 | Inductor | 1 | INDUCTOR RF 1.5nH ±0.05nH 280MA DCr:0.20ohm (0402) -RoHS/No SVHC (2017) | RoHS/ REACH compl. (15 Jan 2019) | Z1 | 1.6nH | 0402 | L1005_L | Murata Electronics | LQP15MN1N6W02D | https://www.findchips.com/detail/LQP15MN1N6W02D | D/M
33 | 030-210163 | Inductor | 1 | INDUCTOR RF 1.5nH ±0.05nH 280MA DCr:0.20ohm (0402) -RoHS/No SVHC (2017) | RoHS/No SVHC (15-Jan-2019) | Z7 | 3.3nH | 0201 | L0603mm | Murata Electronics | LQP03TN3N3B02D | https://www.findchips.com/detail/LQP03TN3N3B02D | D/M/F
34 | 030-210223 | Inductor | 1 | INDUCTOR FIXED 2.2UH ± 20% 1.7A 140 MOHM (0806) | RoHS/ REACH compl. (15 Jan 2019) | L1 | 2.2uH | 0806 (2016 Metric) | L2016 | Murata Electronics | DFE201610E-2R2M=P2 | https://www.findchips.com/detail/DFE201610E-2R2M%3DP2 | D/M/F
35 | 030-230004 | Ferrites_etc | 2 | EMI FB Universal (Power & Signal) 470 ohm±25% 0.5A DCr:0.21 ohm (0603) -RoHS/No SVHC (2017) | RoHS/ REACH compl. (15 Jan 2019) | LP1 LP2 | 500mA_470 OHM | 0603 | L1608 | Murata Electronics | BLM18EG471SN1D | https://www.findchips.com/detail/BLM18EG471SN1D | D/M/F
 |  |  |  | IC
36 | 030-440080 | Special Functions | 1 | IC BLE RF 5.0 SoC with Audio Interface WLCSP34 | RoHS/ REACH compl. (15 Jan 2019) | U1 | DA14531-QFN24 | MSTQFN-24 | DA14531-QFN24 | Dialog Semiconductor | da14531-00000FX2 | x | Dialog Semiconductor
37 | 030-420029 | Memory | 1 | IC FLASH IC FLASH 2MBIT ultra Low Power USON(2x3) | RoHS/ REACH compl. (15 Jan 2019) | U2 | MX25R2035FZUIL0 | USON2x3 | SON50P200X300X55-9M | Macronix | MX25R2035FZUIL0 | https://www.findchips.com/detail/MX25R2035FZUIL0 | D
38 | 030-430061 | Regulator | 1 | IC REG LINEAR 3.3V 300MA 5TSOP | RoHS/ REACH compl. (15 Jan 2019) | U3 | NCP114ASN330T1G | SOT-23-5 Thin, TSOT-23-5 | SOT95P280X110-5N | ON Semiconductor | NCP114ASN330T1G | https://www.findchips.com/detail/NCP114ASN330T1G | D/M/F
39 | 030-440002 | Special Functions | 1 | IC ARM Microcontrollers - MCU 128K Flash, 36K SRAM 32-bit ARM Cortex M3 -RoHS/? | RoHS/ REACH compl. (15 Jan 2019) | U4 | ATSAM3U2CA-CU | TFBGA-100 | tfbga100 | Microchip/ Atmel | ATSAM3U2CA-CU | https://www.findchips.com/detail/ATSAM3U2CA-CU | D
40 | 030-440106 | Special Functions | 1 | Analogue Switch ICs Low-volt Dual SPDT 0.8Ohm w/16KV ESD - UMLP-10 | RoHS Compliant/? | U5 | FSA2259UMX | UMLP-10 | UMLP40P1800X1400X550-10 | On Semi | FSA2259UMX | https://www.findchips.com/detail/FSA2259UMX/2260-ON%20Semiconductor?quantity=1 | D/M
41 | 030-410007 | Logic Ic | 1 | IC Inverters UHS SC-70-5 | ROHS/No SVHC (27-Jun-2018) | U6 | NC7SZ04P5X | SC-70-5 | SOT65P210X110-5N | Fairchild Semiconductor | NC7SZ04P5X | https://www.findchips.com/detail/NC7SZ04P5X | D / M
 |  |  |  | CRYSTAL
42 | 030-720040 | Crystal-Oscillator | 1 | CRYSTAL 32.0000MHZ 6PF ±10ppm tol & stab 4-SMD (2.00mm x 1.60mm) | RoHS/REACH compl. (15 Jan 2019) | Y1 | 32.0000MHZ | 4 pin smd (2.00mm x 1.60mm) | XTAL4p20x16 | Murata | XRCGB32M000F1H00R0 | https://www.findchips.com/detail/XRCGB32M000F1H00R0 | D /M/F
43 | 030-720045 | Crystal-Oscillator | 1 | CRYSTAL 12.0000MHZ 18PF ±20ppm tol., 30ppm stab, 2-SMD (5.00mm x 3.20mm) | RoHS/REACH compl. (15 Jan 2019) | Y3 | 12.0000MHZ | 2-SMD | xtal_5x3 | CTS-Frequency Controls | 445I23D12M00000 | https://www.findchips.com/detail/445I23D12M00000 | D / M
 |  |  |  | Not Populated Parts
x |  | Connector | 1 | CR2032 Cattery holder |  | BT1 | NP |  | bat_blp2016sm
x | 030-110000 | Ceramic | 3 | CAP-No Populated 0402 | x | C8 Z3 Z4 | NP | 0402 | C1005 | x | x | x | x
x | 030-640102 | Header | 1 | HEADER Misc SRSW-type2 STR 2.54mm 1X03 -RoHS/No SVHC | RoHS/No SVHC | J2 | NP_hdr_254_1x03_SRSW | hdr_254_1x03_SRSW -Type2 | hdr_254_1x03_SRSW-T2 | Molex | 0878980306 |  | D/M
x |  |  | 2 |  |  | J3 J4 | NP |  | sck_254_1x08
x | 030-670034 |  | 1 | RF Connectors / SMA Connector Jack, Female Socket 50 Ohm Board Edge, End Launch Solder |  | J5 | NP_142-0761-861 |  | sma_142-0761-861 | Johnson | 142-0761-861
x | 030-010000 | Resistor | 6 | RES-No Populated 0402 | x | R17 R18 R20 R21 R33 R51 | NP | 0402 | R1005 | x | No Populated | x | x
x | 030-420064 | Memory | 1 | IC FLASH 32MBIT 104MHZ 8SOP(208mil) -ROHS/? | RoHS/REACH compl | U2X | NP | 8SOP (0.208") | SOIC127P790X195-8N | Macronix | MX25U3235FM2I-10G |  | D
x | 030-420062 |  | 1 |  |  | U2Y | NP |  | SOIC127P600X175-8N
x | 030-720031 | Crystal-Oscillator | 1 | CRYSTAL 32.7680KHZ 7PF SMD ±20ppm 2-SMD (2.05mm x 1.20mm) | RoHS/? | Y2 | 32.768KHZ | 2PIN 2.05mm x 1.20mm | XTAL_ABS06 | Seiko Instruments | SC20S-7PF20PPM | https://www.findchips.com/detail/SC20S-7PF20PPM | D / M
 |  |  |  | Mechanical / Non-Physical Parts
x | 030-740004 | Mech_Not Physical Parts | 1 | MECH_ Non Physical Antenna Printed_zor_left | x | ANT1 | antenna_zor_left | antenna_zor_l | antenna_zor_l | NA_Mechanical Part | NA_Mechanical Part | na | na
x |  |  | 1 |  |  | T1 | Label_Dialog_L6008 |  | Label_Dialog_L6008
x |  |  | 1 | PCB Test Point |  | TP1 | VLOW |  | tp_bot_sm
x |  |  | 1 | PCB Test Point |  | TP2 | GND |  | tp_bot_sm
x |  |  | 1 | PCB Test Point |  | TP3 | VLDO |  | tp_bot_sm
x |  |  | 1 | PCB Test Point |  | TP4 | 3V3 |  | tp_bot_sm
x |  |  | 1 | PCB Test Point |  | TP5 | VDD_CORE |  | tp_bot_sm
x |  |  | 1 | PCB Test Point |  | TP6 | DBLED |  | tp_bot_sm
x |  |  | 1 | PCB Test Point |  | TP7 | GND |  | tp_bot_sm
x |  |  | 1 | PCB Test Point |  | TP8 | TDI |  | tp_bot_sm
x |  |  | 1 | PCB Test Point |  | TP9 | TCK_SWCLK |  | tp_bot_sm
x |  |  | 1 | PCB Test Point |  | TP10 | TMS_SWDIO |  | tp_bot_sm
x |  |  | 1 | PCB Test Point |  | TP11 | ERASE |  | tp_bot_sm
x |  |  | 1 | PCB Test Point |  | TP12 | NRST |  | tp_bot_sm
x |  |  | 1 | PCB Test Point |  | TP13 | VLED |  | tp_bot_sm
x |  |  | 1 |  |  | TP16 | FIDUCIAL |  | fid_750
x |  |  | 1 |  |  | TP17 | FIDUCIAL |  | fid_750
x |  |  | 1 | PCB Test Point |  | TP18 | LDO_EN |  | tp_bot_sm
x |  |  | 1 | PCB Test Point |  | TP21 | SWDIO |  | tp_bot_sm
x |  |  | 1 | PCB Test Point |  | TP22 | SWCLK |  | tp_bot_sm
x |  |  | 1 |  |  | TP23 | FIDUCIAL |  | fid_750
x |  |  | 1 |  |  | TP24 | FIDUCIAL |  | fid_750
x |  |  | 1 | PCB Test Point |  | TP25 | 5V |  | tp_bot_sm
x |  |  | 1 | PCB Test Point |  | TP30 | SWO/TDO |  | tp_bot_sm
x |  |  | 1 | PCB Test Point |  | TP31 | GND |  | tp_bot_sm
x | 030-740024 | Mech_Not Physical Parts | 1 | MECH_ Non Physical LOGO of MikroBUS | x | TP32 | MikroBUS_LOGO | Mikrobus | Mikrobus | NA_Mechanical Part | NA_Mechanical Part |  | na
x |  |  | 1 | PCB Test Point |  | TP33 | TCTS |  | tp_bot_sm
x |  |  | 1 | PCB Test Point |  | TP34 | TRX |  | tp_bot_sm
x |  |  | 1 | PCB Test Point |  | TP35 | TRTS |  | tp_bot_sm
x |  |  | 1 | PCB Test Point |  | TP36 | TTX |  | tp_bot_sm

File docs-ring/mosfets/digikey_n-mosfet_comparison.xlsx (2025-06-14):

Datasheets | Digi-Key Part Number | Manufacturer Part Number | D [mm] | E [mm] | Area [mm^2] | Comment | Price Digi-Key @ 10k | Price Mouser @ 10k | Stock Digi-Key | Stock Mouser | Rds @ 1.5V | Rds @ 1.8V | Supplier Device Package | Package / Case | Manufacturer | Drain to Source Voltage (Vdss) | Current - Continuous Drain (Id) @ 25°C | Drive Voltage (Max Rds On, Min Rds On) | Rds On (Max) @ Id, Vgs | Vgs(th) (Max) @ Id | Gate Charge (Qg) (Max) @ Vgs | Vgs (Max) | Input Capacitance (Ciss) (Max) @ Vds | Power Dissipation (Max) | Operating Temperature
https://assets.nexperia.com/documents/data-sheet/PMH600UNE.pdf | 1727-8580-1-ND | PMH600UNEH | 0.62 | 0.62 | 0.38 |  | 0.057 | 0.057 | 18591 | 9970 | 1Ohm @ 250mA | 0.75Ohm @ 250mA | DFN0606-3 (SOT8001) | 3-XFDFN | Nexperia USA Inc. | 20V | 800mA (Ta) | 1.2V, 4.5V | 620mOhm @ 600mA, 4.5V | 0.95V @ 250µA | 0.31nC @ 4.5V | ±8V | 21.3pF @ 10V | 370mW (Ta), 2.2W (Tc) | -55°C ~ 150°C (TJ)
https://assets.nexperia.com/documents/data-sheet/PMH550UNE.pdf | 1727-8579-1-ND | PMH550UNEH | 0.62 | 0.62 | 0.38 |  | 0.059 | 0.058 | 60000 | 15921 | 1.2Ohm @ 250mA | 0.75Ohm @ 250mA | DFN0606-3 (SOT8001) | 3-XFDFN | Nexperia USA Inc. | 30V | 770mA (Ta) | 1.5V, 4.5V | 670mOhm @ 770mA, 4.5V | 0.95V @ 250µA | 0.4nC @ 4V | ±8V | 30.3pF @ 15V | 380mW (Ta), 2.8W (Tc) | -55°C ~ 150°C (TJ)
https://www.diodes.com/assets/Datasheets/DMN2990UFZ.pdf | DMN2990UFZ-7BDICT-ND | DMN2990UFZ-7B | 0.62 | 0.62 | 0.38 |  | 0.059 | 0.058 | 10000 | 6488 | 2.4Ohm @ 150mA | 0.75Ohm @ 250mA | X2-DFN0606-3 | 3-XFDFN | Diodes Incorporated | 20V | 250mA (Ta) | 1.2V, 4.5V | 990mOhm @ 100mA, 4.5V | 1V @ 250µA | 0.5nC @ 4.5V | ±8V | 55.2pF @ 16V | 320mW (Ta) | -55°C ~ 150°C (TJ)
//media.digikey.com/pdf/Data%20Sheets/Panasonic%20Electronic%20Components/FK4B01110L1_Spec.pdf | P123938CT-ND | FK4B01110L1 | 0.63 | 0.63 | 0.40 | No alternative, no stock | 0.059 | 0.058 | 1957 | 7306 |  |  | ALGA004-W-0606-RA01 | 4-XFLGA, CSP | Panasonic Electronic Components | 12V | 2.3A (Ta) | 1.5V, 4.5V | 64mOhm @ 1.5A, 4.5V | 1V @ 118µA | 2.55nC @ 4.5V | ±8V | 274pF @ 10V | 340mW (Ta) | -40°C ~ 85°C (TA)
https://www.diodes.com/assets/Datasheets/DMN1260UFA.pdf | DMN1260UFA-7BDICT-ND | DMN1260UFA-7B | 0.85 | 0.65 | 0.55 |  | 0.059 | 0.058 | 0 | 16740 | 1.5Ohm @ 0.5A | 0.25Ohm @ 250mA ? | X2-DFN0806-3 | 3-XFDFN | Diodes Incorporated | 12V | 500mA (Ta) | 1.5V, 4.5V | 366mOhm @ 200mA, 4.5V | 1V @ 250µA | 0.96nC @ 4.5V | ±8V | 60pF @ 10V | 360mW (Ta) | -55°C ~ 150°C (TJ)
https://www.diodes.com/assets/Datasheets/DMN3900UFA.pdf | DMN3900UFA-7BCT-ND | DMN3900UFA-7B | 0.85 | 0.65 | 0.55 |  | 0.078 | 0.066 | 6000 | 2930 | N/A | 0.7Ohm @ 250mA | X2-DFN0806-3 | 3-XFDFN | Diodes Incorporated | 30V | 550mA (Ta) | 1.8V, 4.5V | 760mOhm @ 200mA, 4.5V | 950mV @ 250µA | 0.7nC @ 4.5V | ±8V | 42.2pF @ 25V | 390mW (Ta) | -55°C ~ 150°C (TJ)
https://www.diodes.com/assets/Datasheets/DMN2990UFA.pdf | DMN2990UFA-7BDICT-ND | DMN2990UFA-7B | 0.85 | 0.65 | 0.55 |  | 0.073 | 0.073 | 0 | 9698 | 2.4Ohm @ 330mA | 0.9Ohm @ 250mA | 3-X2-DFN0806 | 3-XFDFN | Diodes Incorporated | 20V | 510mA (Ta) | 1.2V, 4.5V | 990mOhm @ 100mA, 4.5V | 1V @ 250µA | 0.5nC @ 4.5V | ±8V | 27.6pF @ 16V | 400mW (Ta) | -55°C ~ 150°C (TJ)
http://www.ti.com/general/docs/suppproductinfo.tsp?distId=10 | 296-42130-1-ND | CSD17484F4T | 1.00 | 0.60 | 0.60 | Same package - many options. | 0.151 | 0.134 | 173750 | 11270 | N/A | 0.27Ohm @ 0.5A | 3-PICOSTAR | 3-XFDFN | Texas Instruments | 30V | 3A (Ta) | 1.8V, 8V | 121mOhm @ 500mA, 8V | 1.1V @ 250µA | 0.2nC @ 8V | 12V | 195pF @ 15V | 500mW (Ta) | -55°C ~ 150°C (TJ)
http://www.ti.com/general/docs/suppproductinfo.tsp?distId=10 | 296-38621-1-ND | CSD13383F4T | 1.00 | 0.60 | 0.60 |  | 0.077 | 0.076 | 0 | 3403 | N/A | N/A | 3-PICOSTAR | 3-XFDFN | Texas Instruments | 12V | 2.9A (Ta) | 2.5V, 4.5V | 44mOhm @ 500mA, 4.5V | 1.25V @ 250µA | 2.6nC @ 4.5V | ±10V | 291pF @ 6V | 500mW (Ta) | -55°C ~ 150°C (TJ)
http://www.ti.com/general/docs/suppproductinfo.tsp?distId=10 | 296-38912-1-ND | CSD13381F4 | 1.00 | 0.60 | 0.60 |  | 0.078 | 0.077 | 0 | 7969 | N/A | 0.4Ohm @ 0.5A | 3-PICOSTAR | 3-XFDFN | Texas Instruments | 12V | 2.1A (Ta) | 1.8V, 4.5V | 180mOhm @ 500mA, 4.5V | 1.1V @ 250µA | 1.4nC @ 4.5V | 8V | 200pF @ 6V | 500mW (Ta) | -55°C ~ 150°C (TJ)
http://www.ti.com/general/docs/suppproductinfo.tsp?distId=10 | 296-38913-1-ND | CSD17381F4 | 1.00 | 0.60 | 0.60 |  | 0.124 | 0.124 | 5000 | 6410 |  |  | 3-PICOSTAR | 3-XFDFN | Texas Instruments | 30V | 3.1A (Ta) | 1.8V, 4.5V | 109mOhm @ 500mA, 8A | 1.1V @ 250µA | 1.35nC @ 4.5V | 12V | 195pF @ 15V | 500mW (Ta) | -55°C ~ 150°C (TJ)
http://www.ti.com/general/docs/suppproductinfo.tsp?distId=10 | 296-38914-1-ND | CSD17483F4 | 1.00 | 0.60 | 0.60 |  | 0.158 | 0.140 | 5250 | 455 |  |  | 3-PICOSTAR | 3-XFDFN | Texas Instruments | 30V | 1.5A (Ta) | 1.8V, 4.5V | 240mOhm @ 500mA, 8V | 1.1V @ 250µA | 1.3nC @ 4.5V | 12V | 190pF @ 15V | 500mW (Ta) | -55°C ~ 150°C (TJ)
http://www.ti.com/general/docs/suppproductinfo.tsp?distId=10 | 296-49600-1-ND | CSD17382F4 | 1.00 | 0.60 | 0.60 |  | 0.079 | 0.079 | 10000 | 17150 |  |  | 3-PICOSTAR | 3-XFDFN | Texas Instruments | 30V | 2.3A (Ta) | 1.8V, 8V | 64mOhm @ 500mA, 8V | 1.2V @ 250µA | 2.7nC @ 4.5V | 10V | 347pF @ 15V | 500mW (Ta) | -55°C ~ 150°C (TJ)
http://www.ti.com/general/docs/suppproductinfo.tsp?distId=10 | 296-47319-1-ND | CSD17484F4 | 1.00 | 0.60 | 0.60 |  | 0.124 | 0.133 | 0 | 11130 |  |  | 3-PICOSTAR | 3-XFDFN | Texas Instruments | 30V | 3A (Ta) | 1.8V, 8V | 121mOhm @ 500mA, 8V | 1.1V @ 250µA | 1.2nC @ 4.5V | 12V | 195pF @ 15V | 500mW (Ta) | -55°C ~ 150°C (TJ)
http://www.ti.com/general/docs/suppproductinfo.tsp?distId=10 | 296-37780-1-ND | CSD17381F4T | 1.00 | 0.60 | 0.60 |  | 0.087 | 0.073 | 81000 | 6734 |  |  | 3-PICOSTAR | 3-XFDFN | Texas Instruments | 30V | 3.1A (Ta) | 1.8V, 4.5V | 109mOhm @ 500mA, 8V | 1.1V @ 250µA | 1.35nC @ 4.5V | 12V | 195pF @ 15V | 500mW (Ta) | -55°C ~ 150°C (TJ)
http://www.ti.com/general/docs/suppproductinfo.tsp?distId=10 | 296-39991-1-ND | CSD13383F4 | 1.00 | 0.60 | 0.60 |  | 0.087 | 0.073 | 3000 | 3349 |  |  | 3-PICOSTAR | 3-XFDFN | Texas Instruments | 12V | 2.9A (Ta) | 2.5V, 4.5V | 44mOhm @ 500mA, 4.5V | 1.25V @ 250µA | 2.6nC @ 4.5V | ±10V | 291pF @ 6V | 500mW (Ta) | -55°C ~ 150°C (TJ)
http://www.ti.com/general/docs/suppproductinfo.tsp?distId=10 | 296-37779-1-ND | CSD13381F4T | 1.00 | 0.60 | 0.60 |  | 0.084 | 0.083 | 0 | 12862 |  |  | 3-PICOSTAR | 3-XFDFN | Texas Instruments | 12V | 2.1A (Ta) | 1.8V, 4.5V | 180mOhm @ 500mA, 4.5V | 1.1V @ 250µA | 1.4nC @ 4.5V | 8V | 200pF @ 6V | 500mW (Ta) | -55°C ~ 150°C (TJ)
http://www.ti.com/general/docs/suppproductinfo.tsp?distId=10 | 296-37781-1-ND | CSD17483F4T | 1.00 | 0.60 | 0.60 |  | 0.100 | 0.100 | 693000 | 106253 |  |  | 3-PICOSTAR | 3-XFDFN | Texas Instruments | 30V | 1.5A (Ta) | 1.8V, 4.5V | 240mOhm @ 500mA, 8V | 1.1V @ 250µA | 1.3nC @ 4.5V | 12V | 190pF @ 15V | 500mW (Ta) | -55°C ~ 150°C (TJ)
http://www.ti.com/general/docs/suppproductinfo.tsp?distId=10 | 296-44148-1-ND | CSD17382F4T | 1.00 | 0.60 | 0.60 |  | 0.125 | 0.125 | 18000 | 343 |  |  | 3-PICOSTAR | 3-XFDFN | Texas Instruments | 30V | 2.3A (Ta) | 1.8V, 8V | 64mOhm @ 500mA, 8V | 1.2V @ 250µA | 2.7nC @ 4.5V | 10V | 347pF @ 15V | 500mW (Ta) | -55°C ~ 150°C (TJ)
http://www.vishay.com/docs/62978/si8824edb.pdf | SI8824EDB-T2-E1CT-ND | SI8824EDB-T2-E1 | 0.80 | 0.80 | 0.64 | Looks good | 0.152 | 0.166 | 0 | 11340 |  |  | 4-Microfoot | 4-XFBGA | Vishay Siliconix | 20V | - | 1.2V, 4.5V | 75mOhm @ 1A, 4.5V | 800mV @ 250µA | 6nC @ 4.5V | ±5V | 400pF @ 10V | 500mW (Ta) | -55°C ~ 150°C (TJ)
http://www.vishay.com/docs/63682/si8812db.pdf | SI8812DB-T2-E1CT-ND | SI8812DB-T2-E1 | 0.80 | 0.80 | 0.64 |  | 0.088 | 0.087 | 0 | 28185 |  |  | 4-Microfoot | 4-UFBGA | Vishay Siliconix | 20V | - | 1.2V, 4.5V | 59mOhm @ 1A, 4.5V | 1V @ 250µA | 17nC @ 8V | ±5V | - | 500mW (Ta) | -55°C ~ 150°C (TJ)
http://www.vishay.com/docs/62547/si8808db.pdf | SI8808DB-T2-E1CT-ND | SI8808DB-T2-E1 | 0.80 | 0.80 | 0.64 |  | 0.102 | 0.103 | 252000 | 52997 |  |  | 4-Microfoot | 4-UFBGA | Vishay Siliconix | 30V | - | 1.5V, 4.5V | 95mOhm @ 1A, 4.5V | 900mV @ 250µA | 10nC @ 8V | ±8V | 330pF @ 15V | 500mW (Ta) | -55°C ~ 150°C (TJ)
http://www.vishay.com/docs/66700/si8800edb.pdf | SI8800EDB-T2-E1CT-ND | SI8800EDB-T2-E1 | 0.80 | 0.80 | 0.64 |  | 0.088 | 0.087 | 20000 | 13733 |  |  | 4-Microfoot | 4-XFBGA, CSPBGA | Vishay Siliconix | 20V | - | 1.5V, 4.5V | 80mOhm @ 1A, 4.5V | 1V @ 250µA | 8.3nC @ 8V | ±8V | - | 500mW (Ta) | -55°C ~ 150°C (TJ)
http://www.vishay.com/docs/62652/si8806db.pdf | SI8806DB-T2-E1CT-ND | SI8806DB-T2-E1 | 0.80 | 0.80 | 0.64 |  | 0.130 | 0.131 | 27000 | 9874 |  |  | 4-Microfoot | 4-XFBGA | Vishay Siliconix | 12V | - | 1.8V, 4.5V | 43mOhm @ 1A, 4.5V | 1V @ 250µA | 17nC @ 8V | ±8V | - | 500mW (Ta) | -55°C ~ 150°C (TJ)
http://www.vishay.com/docs/62829/si8810edb.pdf | SI8810EDB-T2-E1CT-ND | SI8810EDB-T2-E1 | 0.80 | 0.80 | 0.64 |  | 0.156 | 0.156 | 0 | 13497 |  |  | 4-Microfoot | 4-XFBGA | Vishay Siliconix | 20V | - | 1.5V, 4.5V | 72mOhm @ 1A, 4.5V | 900mV @ 250µA | 8nC @ 8V | ±8V | 245pF @ 10V | 500mW (Ta) | -55°C ~ 150°C (TJ)
http://www.vishay.com/docs/62834/si8816edb.pdf | SI8816EDB-T2-E1CT-ND | SI8816EDB-T2-E1 | 0.80 | 0.80 | 0.64 |  | 0.113 | 0.112 | 0 | 5436 |  |  | 4-Microfoot | 4-XFBGA | Vishay Siliconix | 30V | - | 2.5V, 10V | 109mOhm @ 1A, 10V | 1.4V @ 250µA | 8nC @ 10V | ±12V | 195pF @ 15V | 500mW (Ta) | -55°C ~ 150°C (TJ)
http://www.vishay.com/docs/67999/si8802db.pdf | SI8802DB-T2-E1CT-ND | SI8802DB-T2-E1 | 0.80 | 0.80 | 0.64 |  | 0.193 | 0.210 | 0 | 3260 |  |  | 4-Microfoot | 4-XFBGA | Vishay Siliconix | 8V | - | 1.2V, 4.5V | 54mOhm @ 1A, 4.5V | 700mV @ 250µA | 6.5nC @ 4.5V | ±5V | - | 500mW (Ta) | -55°C ~ 150°C (TJ)
https://assets.nexperia.com/documents/data-sheet/PMCM4401VNE.pdf | 1727-2686-1-ND | PMCM4401VNEAZ | 0.81 | 0.81 | 0.66 | could work | 0.132 | 0.118 | 0 | 13794 |  |  | 4-WLCSP (0.78x0.78) | 4-XFBGA, WLCSP | Nexperia USA Inc. | 12V | 4.7A (Ta) | 1.5V, 4.5V | 42mOhm @ 3A, 4.5V | 900mV @ 250µA | 9nC @ 4.5V | ±8V | 335pF @ 6V | 400mW (Ta), 12.5W (Tc) | -55°C ~ 150°C (TJ)
https://assets.nexperia.com/documents/data-sheet/PMCM440VNE.pdf | 1727-2274-1-ND | PMCM440VNEZ | 0.81 | 0.81 | 0.66 |  | 0.135 | 0.135 | 63000 | 28585 |  |  | 4-WLCSP (0.78x0.78) | 4-XFBGA, WLCSP | Nexperia USA Inc. | 12V | 3.9A (Ta) | 4.5V | 67mOhm @ 3A, 4.5V | 900mV @ 250µA | 8.2nC @ 4.5V | ±8V | 360pF @ 6V | 400mW (Ta), 12.5W (Tc) | -55°C ~ 150°C (TJ)
https://assets.nexperia.com/documents/data-sheet/PMZB600UNE.pdf | 1727-2332-1-ND | PMZB600UNEYL | 1.05 | 0.65 | 0.68 |  | 0.202 | 0.208 | 54000 | 2728 |  |  | DFN1006B-3 | 3-XFDFN | Nexperia USA Inc. | 20V | 600mA (Ta) | 1.2V, 4.5V | 620mOhm @ 600mA, 4.5V | 950mV @ 250µA | 0.7nC @ 4.5V | ±8V | 21.3pF @ 10V | 360mW (Ta), 2.7W (Tc) | -55°C ~ 150°C (TJ)
https://assets.nexperia.com/documents/data-sheet/PMZB290UNE2.pdf | 1727-2328-1-ND | PMZB290UNE2YL | 1.05 | 0.65 | 0.68 |  | 0.198 | 0.214 | 24000 | 4232 |  |  | DFN1006B-3 | 3-XFDFN | Nexperia USA Inc. | 20V | 1.2A (Ta) | 1.5V, 4.5V | 320mOhm @ 1.2A, 4.5V | 950mV @ 250µA | 1.4nC @ 4.5V | ±8V | 46pF @ 10V | 350mW (Ta), 5.43W (Tc) | -55°C ~ 150°C (TJ)
https://assets.nexperia.com/documents/data-sheet/PMZB290UNE.pdf | 1727-1378-1-ND | PMZB290UNE,315 | 1.05 | 0.65 | 0.68 |  | 0.093 | 0.093 | 20000 | 10000 |  |  | DFN1006B-3 | 3-XFDFN | Nexperia USA Inc. | 20V | 1A (Ta) | 1.8V, 4.5V | 380mOhm @ 500mA, 4.5V | 950mV @ 250µA | 0.68nC @ 4.5V | ±8V | 83pF @ 10V | 360mW (Ta), 2.7W (Tc) | -55°C ~ 150°C (TJ)
https://assets.nexperia.com/documents/data-sheet/PMZB290UNE.pdf | 1727-1242-1-ND | PMZB290UN,315 | 1.05 | 0.65 | 0.68 |  | 0.094 | 0.093 | 10000 | 13185 |  |  | DFN1006B-3 | 3-XFDFN | Nexperia USA Inc. | 20V | 1A (Ta) | 1.8V, 4.5V | 380mOhm @ 500mA, 4.5V | 950mV @ 250µA | 0.68nC @ 4.5V | ±8V | 83pF @ 10V | 360mW (Ta), 2.7W (Tc) | -55°C ~ 150°C (TJ)
https://assets.nexperia.com/documents/data-sheet/PMZB600UNEL.pdf | 1727-7378-1-ND | PMZB600UNELYL | 1.05 | 0.65 | 0.68 |  | 0.136 | 0.121 | 0 | 5117 |  |  | DFN1006B-3 | 3-XFDFN | Nexperia USA Inc. | 20V | 600mA (Ta) | 1.2V, 4.5V | 620mOhm @ 600mA, 4.5V | 950mV @ 250µA | 0.7nC @ 4.5V | ±8V | 21.3pF @ 10V | 360mW (Ta) | -55°C ~ 150°C (TJ)
https://assets.nexperia.com/documents/data-sheet/PMZB550UNE.pdf | 1727-2331-1-ND | PMZB550UNEYL | 1.05 | 0.65 | 0.68 |  | 0.206 | 0.373 | 42000 | 11147 |  |  | DFN1006B-3 | 3-XFDFN | Nexperia USA Inc. | 30V | 590mA (Ta) | 1.5V, 4.5V | 670mOhm @ 590mA, 4.5V | 950mV @ 250µA | 1.1nC @ 4.5V | ±8V | 30.3pF @ 15V | 310mW (Ta), 1.67W (Tc) | -55°C ~ 150°C (TJ)
https://assets.nexperia.com/documents/data-sheet/PMZB390UNE.pdf | 1727-2330-1-ND | PMZB390UNEYL | 1.05 | 0.65 | 0.68 |  | 0.207 | 0.230 | 27000 | 8880 |  |  | DFN1006B-3 | 3-XFDFN | Nexperia USA Inc. | 30V | 900mA (Ta) | 1.5V, 4.5V | 470mOhm @ 900mA, 4.5V | 950mV @ 250µA | 1.3nC @ 4.5V | ±8V | 41pF @ 15V | 350mW (Ta), 5.43W (Tc) | -55°C ~ 150°C (TJ)
https://www.diodes.com/assets/Datasheets/DMN2300UFB4.pdf | DMN2300UFB4-7BDICT-ND | DMN2300UFB4-7B | 1.05 | 0.65 | 0.68 |  | 0.096 | 0.095 | 20000 | 19441 |  |  | X2-DFN1006-3 | 3-XFDFN | Diodes Incorporated | 20V | 1.3A (Ta) | 1.5V, 4.5V | 175mOhm @ 300mA, 4.5V | 950mV @ 250µA | 1.6nC @ 4.5V | ±8V | 64.3pF @ 25V | 500mW (Ta) | -55°C ~ 150°C (TJ)
https://assets.nexperia.com/documents/data-sheet/PMZB200UNE.pdf | 1727-2327-1-ND | PMZB200UNEYL | 1.05 | 0.65 | 0.68 |  | 0.166 | 0.159 | 3000 | 3400 |  |  | DFN1006B-3 | 3-XFDFN | Nexperia USA Inc. | 30V | 1.4A (Ta) | 1.5V, 4.5V | 250mOhm @ 1.4A, 4.5V | 950mV @ 250µA | 2.7nC @ 4.5V | ±8V | 89pF @ 15V | 350mW (Ta), 6.25W (Tc) | -55°C ~ 150°C (TJ)
https://assets.nexperia.com/documents/data-sheet/PMZB150UNE.pdf | 1727-2326-1-ND | PMZB150UNEYL | 1.05 | 0.65 | 0.68 |  | 0.206 | 0.211 | 0 | 9761 |  |  | DFN1006B-3 | 3-XFDFN | Nexperia USA Inc. | 20V | 1.5A (Ta) | 1.5V, 4.5V | 200mOhm @ 1.5A, 4.5V | 950mV @ 250µA | 1.6nC @ 4.5V | ±8V | 93pF @ 10V | 350mW (Ta), 6.25W (Tc) | -55°C ~ 150°C (TJ)
https://www.diodes.com/assets/Datasheets/DMN3730UFB4.pdf | DMN3730UFB4-7CT-ND | DMN3730UFB4-7 | 1.05 | 0.65 | 0.68 |  | 0.204 | 0.226 | 0 | 3416 |  |  | X2-DFN1006-3 | 3-XFDFN | Diodes Incorporated | 30V | 750mA (Ta) | 1.8V, 4.5V | 460mOhm @ 200mA, 4.5V | 950mV @ 250µA | 1.6nC @ 4.5V | ±8V | 64.3pF @ 25V | 470mW (Ta) | -55°C ~ 150°C (TJ)
https://toshiba.semicon-storage.com/info/docget.jsp?did=13805&prodName=SSM3K56CT | SSM3K56CTL3FCT-ND | SSM3K56CT,L3F | 1.05 | 0.65 | 0.68 |  | 0.163 | 0.143 | 8000 | 35 |  |  | CST3 | 3-XFDFN | Toshiba Semiconductor and Storage | 20V | 800mA (Ta) | 1.5V, 4.5V | 235mOhm @ 800mA, 4.5V | 1V @ 1mA | 1nC @ 4.5V | ±8V | 55pF @ 10V | 500mW (Ta) | 150°C (TA)
//media.digikey.com/pdf/Data%20Sheets/Panasonic%20Electronic%20Components/FK4B01100L1_Spec.pdf | P123939CT-ND | FK4B01100L1 | 0.84 | 0.84 | 0.71 |  | 0.210 | 0.194 | 3000 | 2975 |  |  | XLGA004-W-0808-RA01 | 4-XFLGA, CSP | Panasonic Electronic Components | 12V | 3.4A (Ta) | 1.5V, 4.5V | 30mOhm @ 1.5A, 4.5V | 1V @ 236µA | 5.8nC @ 4.5V | ±8V | 275pF @ 10V | 360mW (Ta) | -40°C ~ 85°C (TA)
https://www.diodes.com/assets/Datasheets/ds31983.pdf | DMN2600UFB-7DICT-ND | DMN2600UFB-7 | 1.07 | 0.68 | 0.73 |  | 0.143 | 0.143 | 18000 | 8855 |  |  | 3-X1DFN1006 | 3-UFDFN | Diodes Incorporated | 25V | 1.3A (Ta) | 1.8V, 4.5V | 350mOhm @ 200mA, 4.5V | 1V @ 250µA | 0.85nC @ 4.5V | ±8V | 70.13pF @ 15V | 540mW (Ta) | -55°C ~ 150°C (TJ)
https://www.diodes.com/assets/Datasheets/ds31963.pdf | DMN2400UFB-7DICT-ND | DMN2400UFB-7 | 1.07 | 0.68 | 0.73 |  | 0.210 | 0.194 | 6000 | 0 |  |  | 3-X1DFN1006 | 3-XFDFN | Diodes Incorporated | 20V | 750mA (Ta) | 1.8V, 4.5V | 550mOhm @ 600mA, 4.5V | 900mV @ 250µA | 0.5nC @ 4.5V | ±12V | 36pF @ 16V | 470mW (Ta) | -55°C ~ 150°C (TJ)
https://www.diodes.com/assets/Datasheets/DMN1150UFB.pdf | DMN1150UFB-7BDICT-ND | DMN1150UFB-7B | 1.07 | 0.68 | 0.73 |  | 0.128 | 0.128 | 10000 | 15190 |  |  | 3-X1DFN1006 | 3-UFDFN | Diodes Incorporated | 12V | 1.41A (Ta) | 1.8V, 4.5V | 150mOhm @ 1A, 4.5V | 1V @ 250µA | 1.5nC @ 4.5V | ±6V | 106pF @ 10V | 500mW (Ta) | -55°C ~ 150°C (TJ)
https://www.diodes.com/assets/Datasheets/DMN3730UFB.pdf | DMN3730UFB-7CT-ND | DMN3730UFB-7 | 1.07 | 0.68 | 0.73 |  | 0.144 | 0.117 | 27750 | 5512 |  |  | 3-X1DFN1006 | 3-UFDFN | Diodes Incorporated | 30V | 750mA (Ta) | 1.8V, 4.5V | 460mOhm @ 200mA, 4.5V | 950mV @ 250µA | 1.6nC @ 4.5V | ±8V | 64.3pF @ 25V | 470mW (Ta) | -55°C ~ 150°C (TJ)
https://www.diodes.com/assets/Datasheets/DMN21D2UFB.pdf | DMN21D2UFB-7BDICT-ND | DMN21D2UFB-7B | 1.07 | 0.68 | 0.73 |  | 0.175 | 0.192 | 0 | 4432 |  |  | 3-X1DFN1006 | 3-UFDFN | Diodes Incorporated | 20V | 760mA (Ta) | 1.5V, 4.5V | 990mOhm @ 100mA, 4.5V | 1V @ 250µA | 0.93nC @ 10V | ±12V | 27.6pF @ 16V | 380mW (Ta) | -55°C ~ 150°C (TJ)
https://assets.nexperia.com/documents/data-sheet/PMXB43UNE.pdf | 1727-1476-1-ND | PMXB43UNEZ | 1.10 | 1.00 | 1.10 |  | 0.155 |  | 0 |  |  |  | DFN1010D-3 | 3-XDFN Exposed Pad | Nexperia USA Inc. | 20V | 3.2A (Ta) | 1.5V, 4.5V | 54mOhm @ 3.2A, 4.5V | 900mV @ 250µA | 10nC @ 4.5V | ±8V | 551pF @ 10V | 400mW (Ta), 8.33W (Tc) | -55°C ~ 150°C (TJ)
https://assets.nexperia.com/documents/data-sheet/PMXB40UNE.pdf | 1727-1475-1-ND | PMXB40UNEZ | 1.10 | 1.00 | 1.10 |  | 0.147 | 0.119 | 10000 | 2721 |  |  | DFN1010D-3 | 3-XDFN Exposed Pad | Nexperia USA Inc. | 12V | 3.2A (Ta) | 1.2V, 4.5V | 45mOhm @ 3.2A, 4.5V | 900mV @ 250µA | 11.6nC @ 4.5V | ±8V | 556pF @ 10V | 400mW (Ta), 8.33W (Tc) | -55°C ~ 150°C (TJ)
https://www.diodes.com/assets/Datasheets/DMN1045UFR4.pdf | DMN1045UFR4-7DICT-ND | DMN1045UFR4-7 | 1.05 | 1.05 | 1.10 |  | 0.177 | 0.169 | 3000 | 3655 |  |  | X2-DFN1010-3 | 3-XFDFN | Diodes Incorporated | 12V | 3.2A (Ta) | 1.5V, 4.5V | 45mOhm @ 3.2A, 4.5V | 1V @ 250µA | 4.8nC @ 4.5V | ±8V | 375pF @ 10V | 500mW (Ta) | -55°C ~ 150°C (TJ)
//media.digikey.com/pdf/Data%20Sheets/Panasonic%20Electronic%20Components/FK4B01120L1_Spec.pdf | P123940CT-ND | FK4B01120L1 | 1.05 | 1.05 | 1.10 |  | 0.103 | 0.103 | 30000 | 19650 |  |  | ULGA004-W-1010-RA01 | 4-XFLGA, CSP | Panasonic Electronic Components | 12V | 3.9A (Ta) | 1.5V, 4.5V | 24mOhm @ 1.5A, 4.5V | 1V @ 394µA | 7nC @ 4.5V | ±8V | 490pF @ 10V | 370mW (Ta) | -40°C ~ 85°C (TA)
https://assets.nexperia.com/documents/data-sheet/PMCM6501UNE.pdf | 1727-7626-1-ND | PMCM6501UNEZ | 1.51 | 1.01 | 1.53 |  | 0.172 | 0.151 | 11750 | 2862 |  |  | 6-WLCSP (1.48x.98) | 6-XFBGA, WLCSP | Nexperia USA Inc. | 20V | 8.7A (Ta) | 1.5V, 4.5V | 21mOhm @ 3A, 4.5V | 0.9V @ 250µA | 6.2nC @ 4.5V | ±8V | 105pF @ 10V | 400mW | 150°C (TJ)
https://assets.nexperia.com/documents/data-sheet/PMCM6501VNE.pdf | 1727-2688-1-ND | PMCM6501VNEZ | 1.51 | 1.01 | 1.53 |  | 0.206 | 0.214 | 0 | 1872 |  |  | 6-WLCSP (1.48x.98) | 6-XFBGA, WLCSP | Nexperia USA Inc. | 12V | 7.3A (Ta) | 1.5V, 4.5V | 18mOhm @ 3A, 4.5V | 900mV @ 250µA | 24nC @ 4.5V | ±8V | 920pF @ 6V | 556mW (Ta), 12.5W (Tc) | -55°C ~ 150°C (TJ)
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

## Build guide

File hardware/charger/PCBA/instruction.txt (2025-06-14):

Please use M13 (3D body layer) for pin 1 indicators.
Please use M15 (Top assembly layer) for component placement along the P&P (pick and place) CSV file.

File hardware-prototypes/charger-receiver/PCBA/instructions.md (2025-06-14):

Please use M13 (3D body layer) for pin 1 indicators for IC.
Please use M15 (Top assembly layer) for component placement along the P&P (pick and place) CSV file.
U1 is BGA with solder balls and doesn't need paste, that's why it doesn't have stencil opening.

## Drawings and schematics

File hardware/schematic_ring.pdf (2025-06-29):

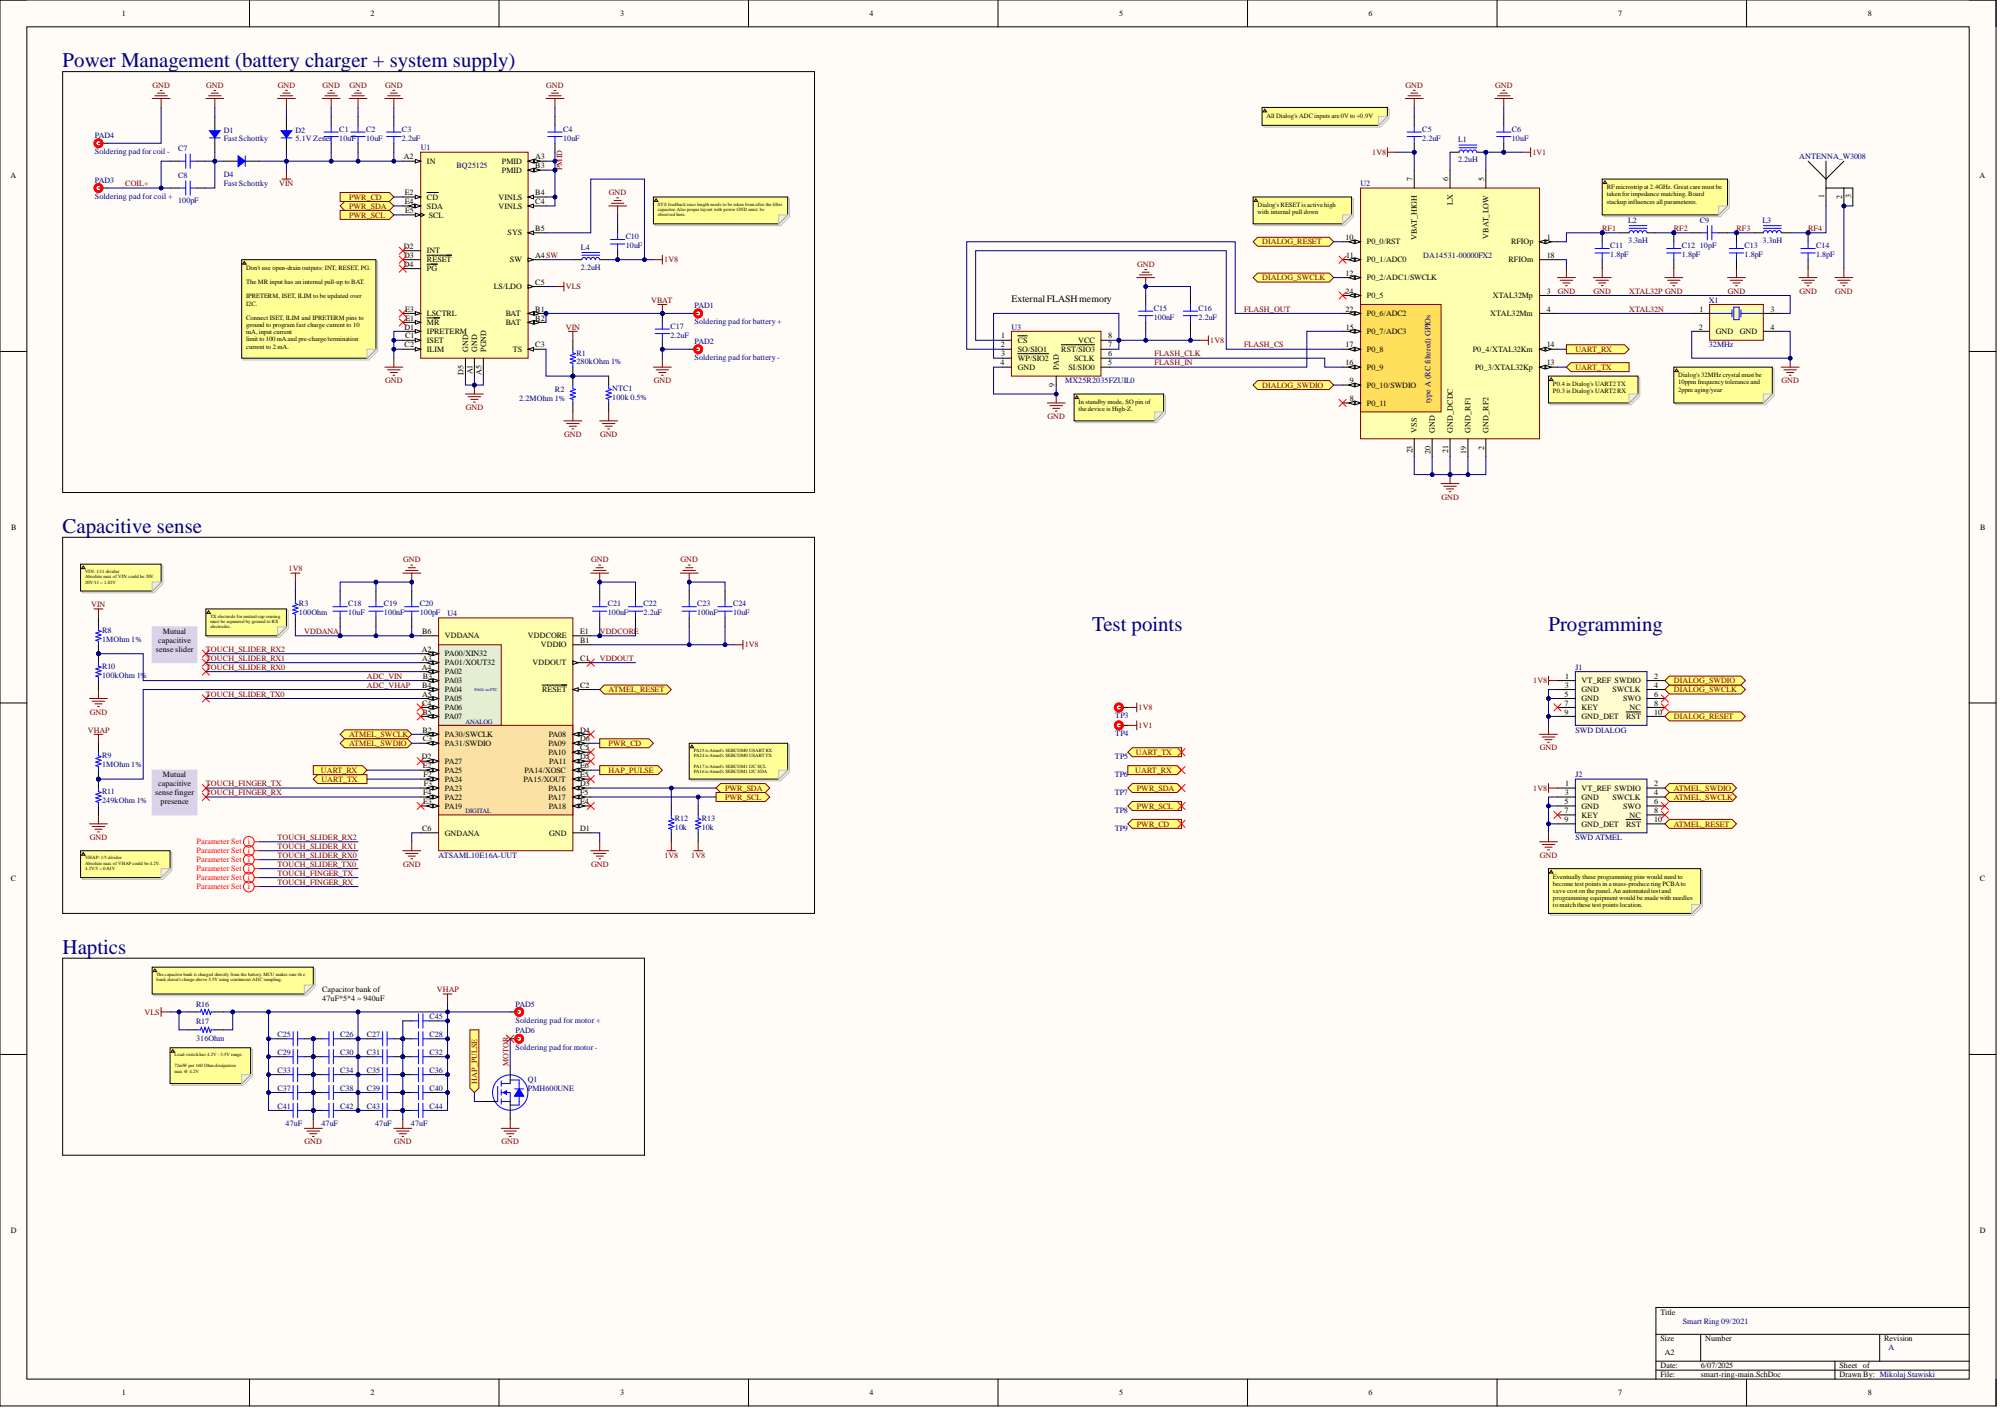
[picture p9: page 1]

Power Management (battery charger + system supply)

All Dialog's ADC inputs are 0V to +0.9V

Soldering pad for coil -

Soldering pad for coil +

RF microstrip at 2.4GHz. Great care must be
taken for impedance matching. Board
stackup influences all parameteres.

SYS feedback trace length needs to be taken from after the filter
capacitor. Also proper layout with power GND must be
observed here.

Dialog's RESET is active high
with internal pull down

Don't use open-drain outputs: INT, RESET, PG.

The MR input has an internal pull-up to BAT.

IPRETERM, ISET, ILIM to be updated over

Connect ISET, ILIM and IPRETERM pins to
ground to program fast charge current to 10
mA, input current
limit to 100 mA and pre-charge/termination
current to 2 mA.

Soldering pad for battery +

GND 20 type A (RC filtered) GPIOs

Soldering pad for battery -

Dialog's 32MHz crystal must be
10ppm frequency tolerance and
2ppm aging/year

In standby mode, SO pin of
the device is High-Z.

VIN: 1/11 divider
Absolute max of VIN could be 20V.

TX electrode for mutual-cap sensing
must be separated by ground to RX
electrodes.

PA25 is Atmel's SERCOM0 USART RX
PA24 is Atmel's SERCOM0 USART TX

VHAP: 1/5 divider
Absolute max of VHAP could be 4.2V.

Eventually these programming pins would need to
become test pointsin a mass-produce ring PCBAto
save cost on the panel. An automated test and
programming equipment would be made with needles
to match these test pointslocation.

The capacitor bank is charged directly from the battery. MCU makes sure the
bank doesn't charge above 3.5V using continuous ADC sampling.

Soldering pad for motor +
PAD6

MOTOR-
Soldering pad for motor -

Load switch has 4.2V - 3.5V range.

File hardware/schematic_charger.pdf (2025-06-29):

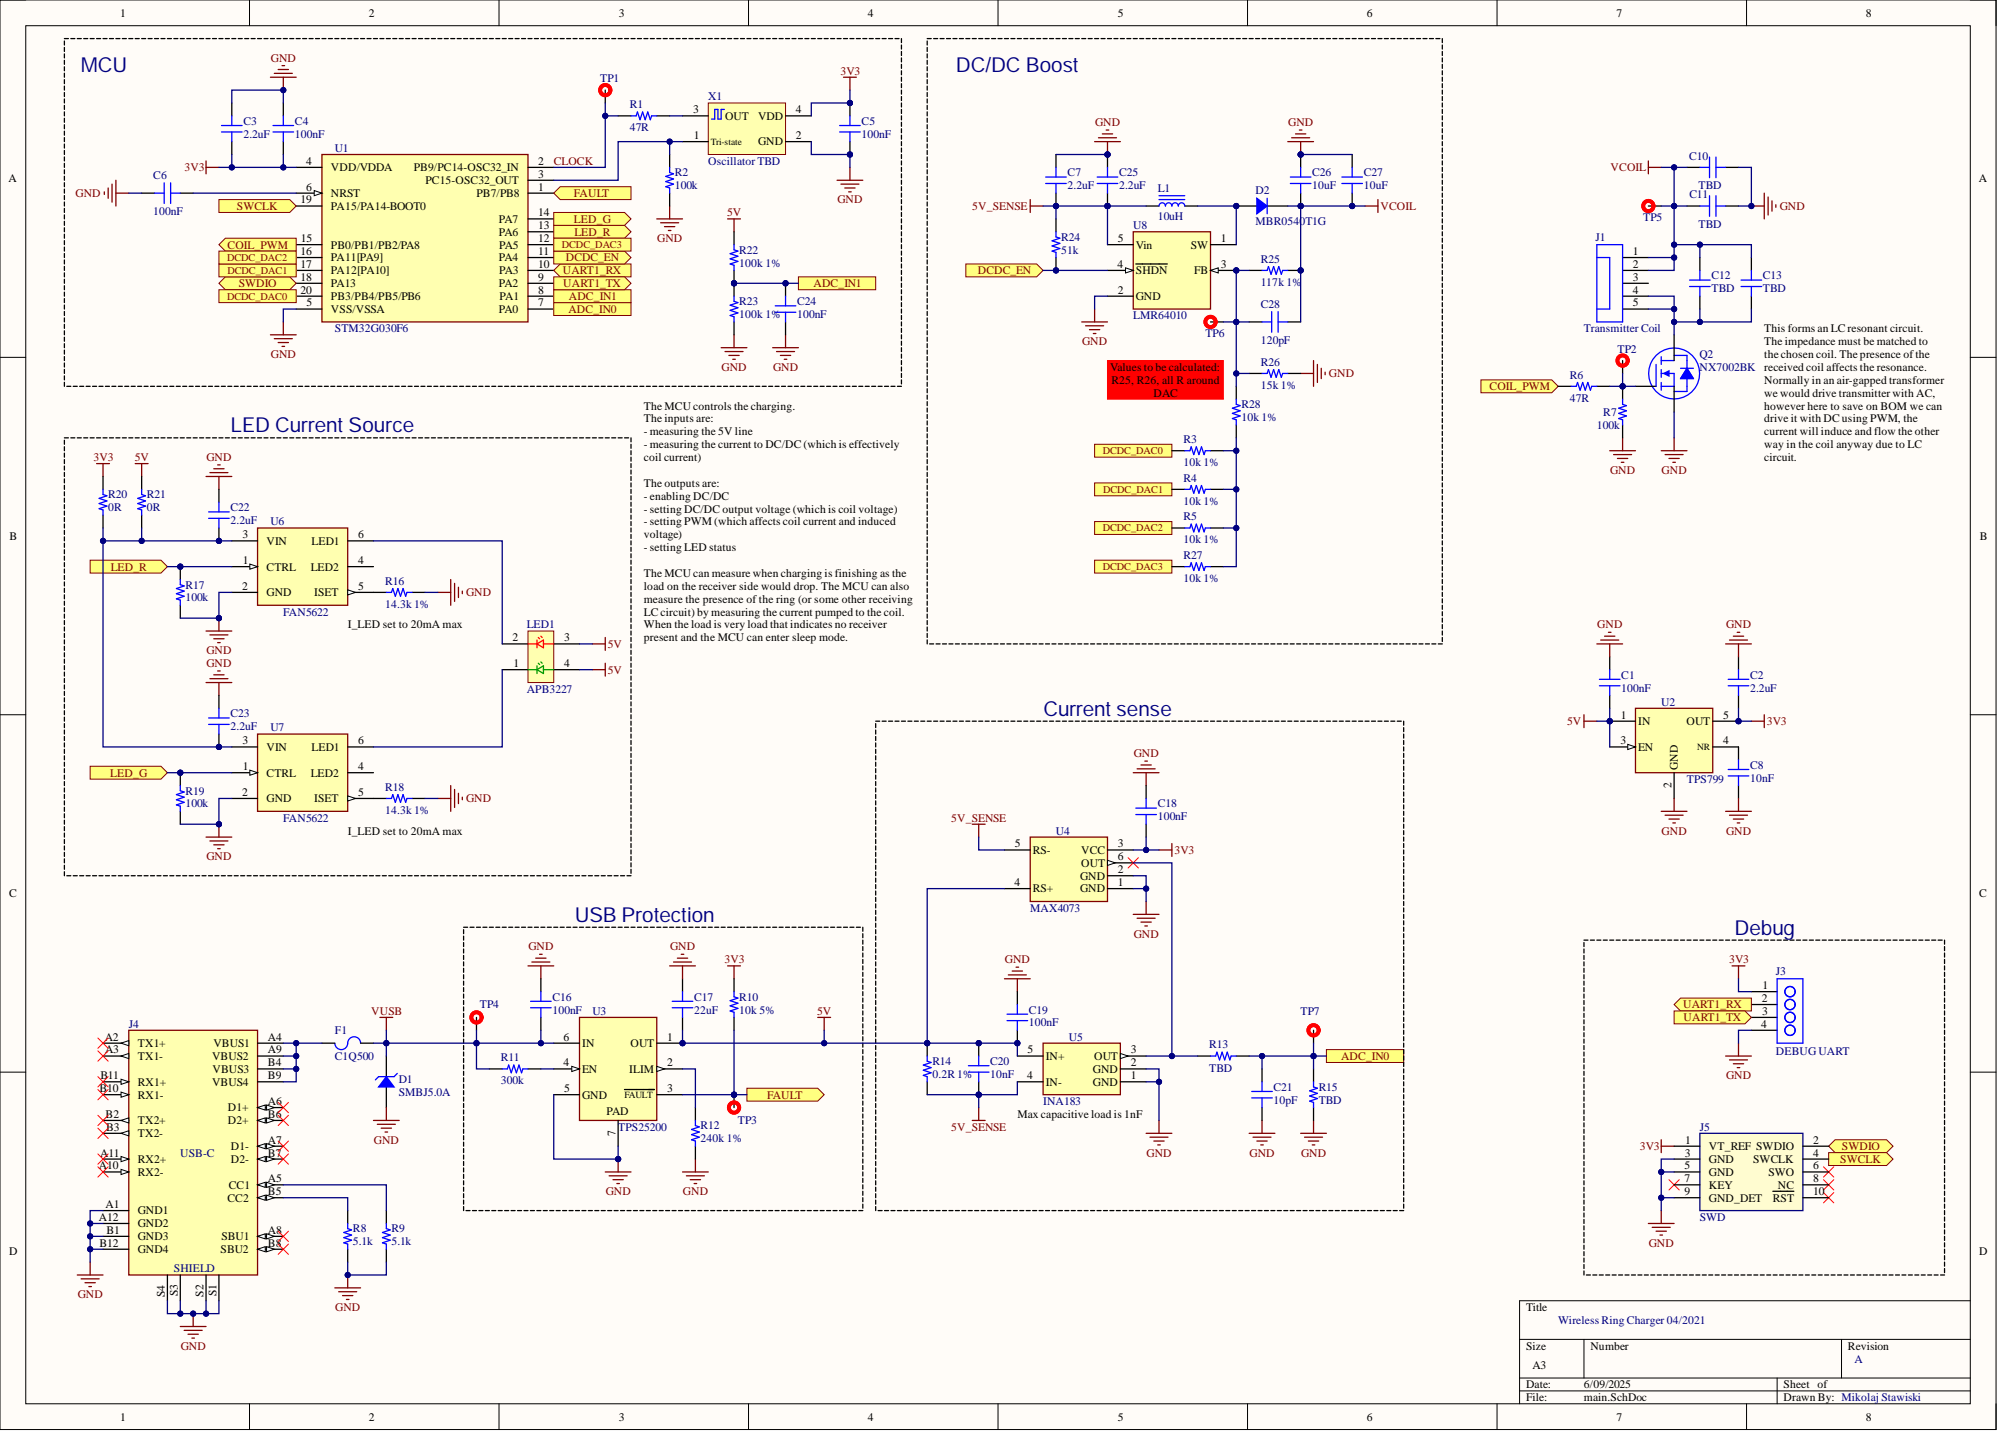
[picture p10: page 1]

he MCU can meas
oad

he MCU can al

he MCU can en

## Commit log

2025-06-14 Add docs
    [digikey_n-mosfet_comparison.xlsx, ntcg104ed104dt1x.csv]
2025-06-14 Add hardware prototypes
    [Assembly_BOM.xlsx, Assembly_P&P.csv, BOM.xlsx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]
2025-06-14 Add main hardware
    [BOM and P&P.xlsx, BOM.xlsx, P&P.csv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]
2025-06-29 Add schematics in PDF.
2025-07-06 Add touch sensor image.
